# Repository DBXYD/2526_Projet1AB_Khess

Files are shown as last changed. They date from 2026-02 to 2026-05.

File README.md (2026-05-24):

# 🎓 2526_Projet1AB_Khess
> [!Note]
> Projet de 1ère année ENSEA sur une caisse enregistreuse pour la K-Fet.

> [!Important]
> Ce projet reprend en partie le travail de Matis Garbez, disponible sur [2425_Maker_CashRegister](https://github.com/Volcanite/2425_Maker_CashRegister/).




[]()

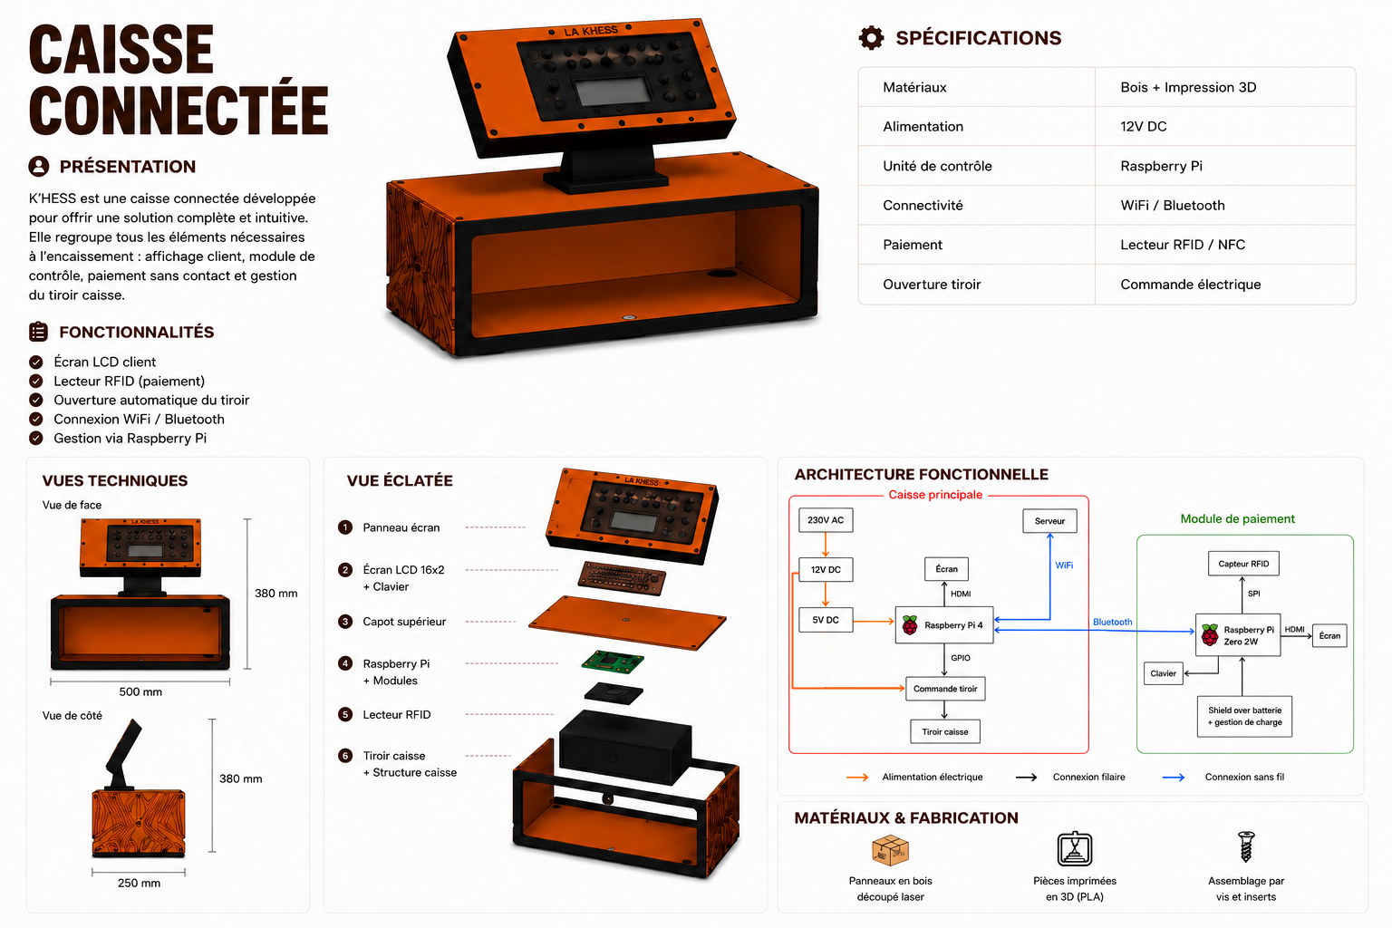
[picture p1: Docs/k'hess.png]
Illustration


## 📋 Sommaire
- [Cahier des charges](#cahier-des-charges)
	- [Caisse enregistreuse portable avec écran tactile](#caisse-enregistreuse-portable-avec-%C3%A9cran-tactile)
	- [Contraintes](#contraintes)
- [Hardware](#hardware)
- [Modèle 3D de la caisse](#mod%C3%A8le-3d-de-la-caisse)
- [Partie Logicielle (Software)](#partie-logicielle-software)
	- [Accès au Code Source et Déploiement](#acc%C3%A8s-au-code-source-et-d%C3%A9ploiement)
	- [Architecture de la Base de Données](#architecture-de-la-base-de-donn%C3%A9es)
- [Technologies utilisées](#technologies-utilis%C3%A9es)
- [Avancée du projet](#avanc%C3%A9e-du-projet)
	- [Journal de bord](#journal-de-bord)
	- [Ce qui a été réalisé](#ce-qui-a-%C3%A9t%C3%A9-r%C3%A9alis%C3%A9)
	- [Ce qui n'a pas (encore) été réalisé](#ce-qui-na-pas-encore-ete-r%C3%A9alis%C3%A9)
	- [Problèmes rencontrés et solutions trouvées](#probl%C3%A8mes-rencontr%C3%A9s-et-solutions-trouv%C3%A9es)
	- [Améliorations possibles](#am%C3%A9liorations-possibles)
- [Membres du projet](#membres-du-projet)
- [Licence](#licence)

## 📝 Cahier des charges 

### 📱 Caisse enregistreuse portable avec écran tactile 
* Interface utilisateur intuitive
* Gestion des produits et des prix
* Paiement avec carte étudiante

### ⚠️ Contraintes 
* Portabilité (batterie) : terminal de paiement
* Fiabilité des transactions
* Sécurité des données

## 🔧 Hardware 
Voir [Hardware/README.md](Hardware/README.md).

## 🖨️ Modèle 3D de la caisse 
La caisse automatique est consituée de 3 éléments :
- la caisse entière avec le socle
- le module de paiement
- le support pour la tablette
  
La modélisation 3D de ces différentes pièces à été réaliser avec le logiciel Onshape, voici les liens correspondant : 
* [Caisse entière avec socle](3D/Caisse%20entière%20avec%20socle.stl) 
* [Module paiement final](3D/Module%20payement%20final.stl)
* [Support tablette final](3D/Support%20tablette%20final.stl)

## 💻 Partie Logicielle (Software) 
Cette section regroupe l'ensemble du code source de l'application web de la caisse connectée, développée avec le framework **Django** (Python).

### 🔗 Accès au Code Source et Déploiement 

> **Note sur le dépôt :** Suite à des difficultés techniques lors de la synchronisation et de l'envoi du code sur le dépôt partagé de l'équipe, la version la plus récente et totalement à jour de l'application a été temporairement hébergée sur mon espace personnel.

* **Code source à jour :** Vous pouvez consulter et récupérer l'intégralité du projet en [cliquant directement sur ce lien vers mon dépôt personnel](https://github.com/zhang-estelle/DatabaseCashRegister).
* **Guide d'installation :** Pour faire fonctionner le code facilement sur votre machine, j'ai rédigé un guide pas-à-pas. Ce tutoriel recense également l'ensemble des blocages et des problèmes techniques que j'ai rencontrés durant le développement ainsi que leurs solutions. [Consulter le tutoriel de configuration Django](Docs/TutoDjango.md).

### 🗄️ Architecture de la Base de Données 

Le système s'appuie sur une base de données relationnelle structurée pour gérer les profils des étudiants, leurs soldes (cotisants ou non), le catalogue de la K-FET et l'historique des ventes.

* **Modèle Conceptuel :** Pour comprendre l'organisation de nos tables, vous pouvez [accéder au schéma graphique dbdiagram](Docs/dbdiagram.pdf).

## ⚙️ Technologies utilisées 
- Python
- Django
- Raspberry Pi
- KiCad
- Onshape
- Impression 3D

## ✅ Avancée du projet 

### 📓 Journal de bord 
Voir [Journal_de_bord.md](Docs/Journal_de_bord.md).

### ✅ Ce qui a été réalisé 
* Prise en main du projet
* Création des PCB
* Soudure des PCB
* Développement du site internet/ interface vendeur avec gestion des stocks, des commandes
* Modification 3D de la caisse en changeant les dimensions du socle soutenant la tablette
* Modélisation 3D du module de paiement avec plusieurs variantes afin de correspondre à la taille du PCB contenu à l'intérieur
* Développement du code du module de payement
* Modification 3D de la caisse en changeant le support tablette se mettant sur le socle
* Test du PCB

### ❌ Ce qui n'a pas (encore) été réalisé 
* Assemblage de l'ensemble

### 🛠️ Problèmes rencontrés et solutions trouvées 
Modélisation 3D:
- La taille du support de tablette était trop petite ( impossibilité de passer les câbles HDMI et USB vers la caisse automatique ). 
On a du imprimer plusieurs fois le support pour trouver la taille adéquate.
- Les trous pour fixer le support de tablette à son support n'étaient pas au bonne endroit après l'impression, on a du percer avec une perceuse les trous pour fixer le support correctement. 
- Problèmes usuels d'impression 3D.

### 💡 Améliorations possibles 
* Revoir le design de la caisse
* Améliorer le site internet

## 👥 Membres du projet 
|  |  |  |  |  |  |  |
| :---: | :---: | :---: | :---: | :---: | :---: | :---: |
| [@Ahhj93](https://github.com/Ahhj93)<br>Bryan-Sowanna Ing | [@NKRIMAT](https://github.com/NKRIMAT)<br>Naïm Krimat | [@Margaux-Lapl](https://github.com/Margaux-Lapl)<br>Margaux Laplante | [@StrangeKobe](https://github.com/StrangeKobe)<br>Rayan Laghouane | [@zhang-estelle](https://github.com/zhang-estelle)<br>Estelle Zhang | [@ClementJ493](https://github.com/ClementJ493)<br>Clément Jouneau | [@rim-05-mma](https://github.com/rim-05-mma)<br>Rim Bouchikhi |

## 📄 Licence 
Ce projet est distribué sous la licence MIT — voir [LICENSE](LICENSE).

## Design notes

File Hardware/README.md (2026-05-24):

# 🔧 Hardware
[]()
[]()
 
## 📋 Sommaire
- [Schéma d'architecture](#schema-architecture)
- [PCB_Khess_Cash_Drawer](#pcb_khess_cash_drawer)
    - [Schéma](#sch%C3%A9ma)
    - [Liste des composants du PCB](#liste-des-composants-du-pcb)
    - [Liste des composants autres](#liste-des-composants-autres)
    - [Justification des choix techniques](#justification-des-choix-techniques)
        - [Architecture d’alimentation](#architecture-dalimentation)
        - [Protections électriques](#protections-%C3%A9lectriques)
        - [Commande du tiroir caisse](#commande-du-tiroir-caisse)
    - [Ouverture du tiroir caisse (Raspberry Pi 4)](#ouverture-du-tiroir-caisse-raspberry-pi-4)
    - [PCB](#pcb)
- [PCB_Khess_Module_Payment](#pcb_khess_module_payment)
    - [Schéma](#sch%C3%A9ma-1)
    - [Liste des composants du PCB](#liste-des-composants-du-pcb-1)
    - [Liste des composants autres](#liste-des-composants-autres-1)
    - [Justification des choix techniques](#justification-des-choix-techniques-1)
        - [Raspberry Pi Zero 2W](#raspberry-pi-zero-2w)
        - [Interface RFID](#interface-rfid)
        - [Interface écran](#interface-%C3%A9cran)
        - [Clavier numérique](#clavier-num%C3%A9rique)
    - [PCB](#pcb-1)

## 🔎 Schéma d'architecture 

Voici une représentation Mermaid du schéma :

```mermaid
flowchart LR
    subgraph Caisse_principale[ Caisse principale ]
        A230(230V AC) --> A12(12V DC)
        A12 --> A5(5V DC)
        A5 --> RPi4[Raspberry Pi 4]
        A12 --> CmdT[Commande tiroir]
        CmdT --> Tiroir[Tiroir caisse]
        RPi4 -->|HDMI| Ecran[Ecran]
        RPi4 -->|GPIO| CmdT
        RPi4 -->|WiFi| Serveur[Serveur]
    end

    subgraph Module_paiement[ Module de paiement ]
        Shield[Shield + gestion batterie] --> RPi0[Raspberry Pi Zero 2W]
        RPi0 -->|HDMI| Ecran2[Ecran]
        RPi0 -->|SPI| RFID[Capteur RFID]
        RPi0 --> Clavier[Clavier]
    end

    RPi4 -->|Bluetooth| RPi0
```

## 🧾 PCB_Khess_Cash_Drawer 
### 🗺️ Schéma 
<details>
<summary>Afficher le schéma</summary>

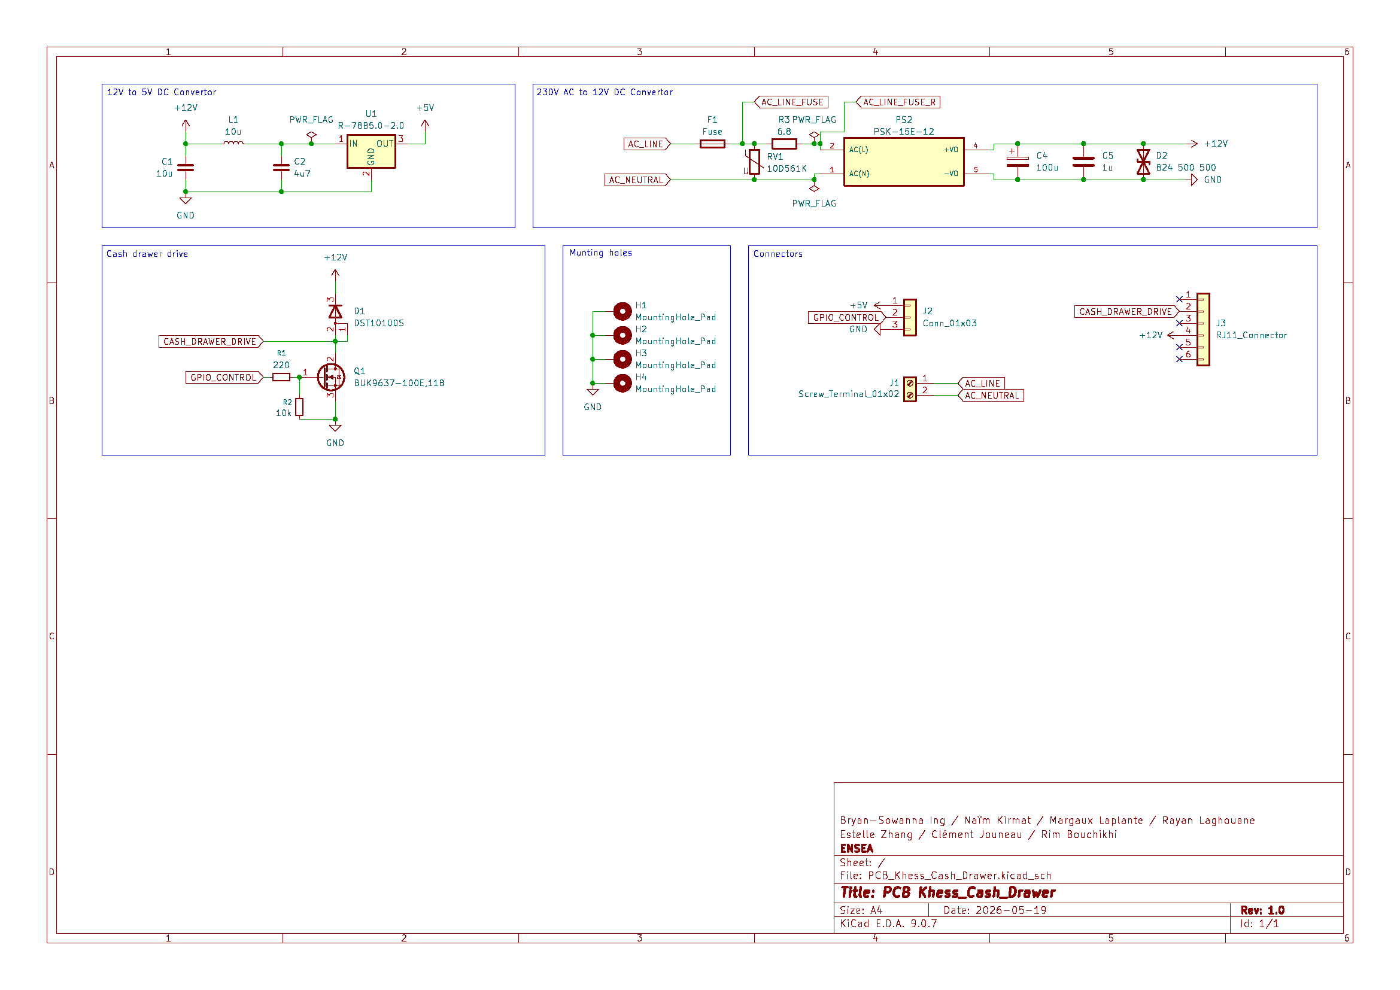
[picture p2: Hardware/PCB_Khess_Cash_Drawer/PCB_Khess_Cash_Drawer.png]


</details>

### 🔩 Liste des composants du PCB 

* Convertisseur 12V à 5V DC
    * 1 Convertisseur R-78B5.0-2.0 ([datasheet](/Datasheets/PCB_Khess_Cash_Drawer/R-78B-2.0.pdf))
    * 1 Condensateur 10uF
    * 1 Condensateur 4,7uF
    * 1 Bobine 10uH

* Conventisseur 230V à 12V DC
    * 1 Porte-fusible
    * 1 Convertisseur PSK-15E-12 ([datasheet](/Datasheets/PCB_Khess_Cash_Drawer/psk-15e.pdf))
    * 1 Condensateur 100uF
    * 1 Condensateur 1uF
    * 1 Diode TVS (824 500 500) ([datasheet](/Datasheets/PCB_Khess_Cash_Drawer/824500500.pdf))
    * 1 Résistance bobinée 6,8 Ohm (remplacée par un fil) ([datasheet](/Datasheets/PCB_Khess_Cash_Drawer/ac_ac-at_ac-ni.pdf))
    * 1 Varistance TVS 10D561K (non mise) ([datasheet](/Datasheets/PCB_Khess_Cash_Drawer/mov10d.pdf))

* Commande du tiroir caisse
    * 1 Diode DST10100S ([datasheet](/Datasheets/PCB_Khess_Cash_Drawer/littelfuse-rectifier-DST10100S-datasheet.pdf))
    * 1 Transistor BUK9637-100E,118 ([datasheet](/Datasheets/PCB_Khess_Cash_Drawer/BUK9637-100E.pdf))
    * 1 Résistance 220 Ohm
    * 1 Résistance 10k Ohm

* Connecteurs
    * 1 Connecteur 01x03
    * 1 Connecteur RJ11, remplacée par 1 Connecteur 01x02
    * 1 Bornier à vis 01x02
    * 1 Écran tactile

### 📦 Liste des composants autres 

* Tiroir caisse avec connecteur standard RJ11, remplacée par des connecteurs simples
* Câble d'alimentation
* Raspberry Pi 4

## ⚙️ Justification des choix techniques 

### 🔌 Architecture d’alimentation 

L’alimentation du système est réalisée en deux étapes afin d’assurer une conversion efficace et stable :

1. Conversion du secteur 230V AC vers 12V DC ;
2. Conversion du 12V DC vers 5V DC.

Le module **PSK-15E-12** a été choisi car il permet :
- une intégration compacte directement sur le PCB ;
- une puissance suffisante pour alimenter le tiroir caisse et les circuits logiques.

Le convertisseur **R-78B5.0-2.0** a été préféré à un régulateur linéaire classique pour son excellent rendement énergétique. Cela permet - d’éviter l’ajout d’un dissipateur thermique ;
- d’assurer une alimentation stable du Raspberry Pi.

Les condensateurs et la bobine de filtrage permettent de réduire les parasites haute fréquence et d’améliorer la stabilité des tensions d’alimentation.

### 🛡️ Protections électriques 

Plusieurs composants de protection ont été ajoutés afin d’améliorer la robustesse du système :

- le porte-fusible protège la carte en cas de court-circuit ;
- la diode TVS protège contre les surtensions transitoires ;
- la varistance devait initialement renforcer la protection contre les pics secteur ;
- les condensateurs participent au filtrage des perturbations électromagnétiques.

Ces protections sont importantes car le système est directement relié au secteur et pilote une charge inductive.

### ⚡ Commande du tiroir caisse 

Le tiroir caisse est commandé via un MOSFET de puissance **BUK9637-100E**. Ce composant a été choisi pour :
- sa faible résistance à l’état passant ;
- sa capacité à commuter des courants importants ;
- sa compatibilité avec les niveaux logiques du Raspberry Pi.

La diode **DST10100S** agit comme diode de roue libre afin d’absorber les surtensions générées lors de la coupure du courant dans l’électroaimant du tiroir caisse.

La résistance de 220 Ω limite le courant de commande du MOSFET tandis que la résistance de 10 kΩ garantit son extinction au démarrage.

### 🚪 Ouverture du tiroir caisse (Raspberry Pi 4) 

L’ouverture du tiroir caisse se fait via le PCB :

1. La **Raspberry Pi 4** envoie un signal de commande sur un **GPIO** ;
2. Le GPIO pilote la grille du **MOSFET** sur le PCB ;
3. Le MOSFET commute l’alimentation **12V** de l’électroaimant du tiroir ;
4. Le tiroir caisse s’ouvre pendant l’impulsion.

Nous n’avions pas de port **RJ11** disponible sur notre montage.  
Nous avons donc remplacé les connecteurs RJ11 par des **pinheaders**.

### 🧩 PCB 
<details>
<summary>Voir PCB (face côté avant)</summary>

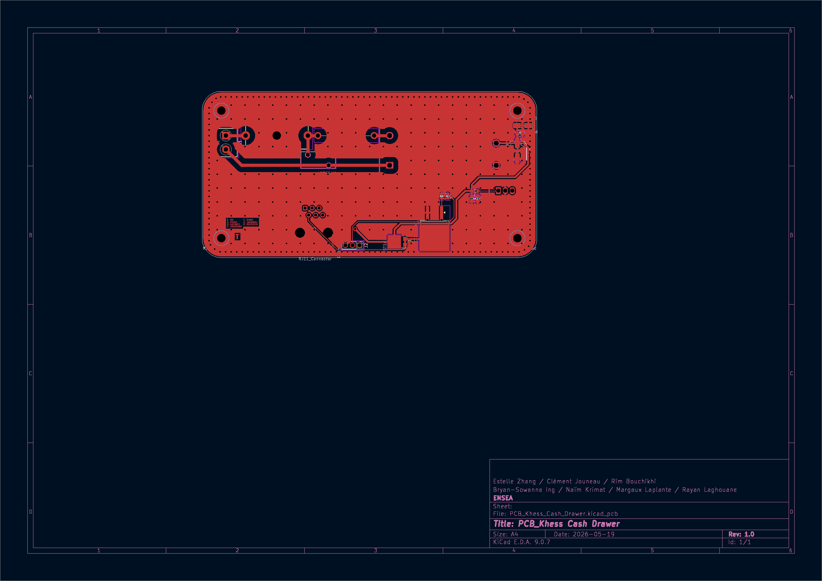
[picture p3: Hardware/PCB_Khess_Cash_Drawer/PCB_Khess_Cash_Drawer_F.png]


</details>

<details>
<summary>Voir PCB (face arrière)</summary>

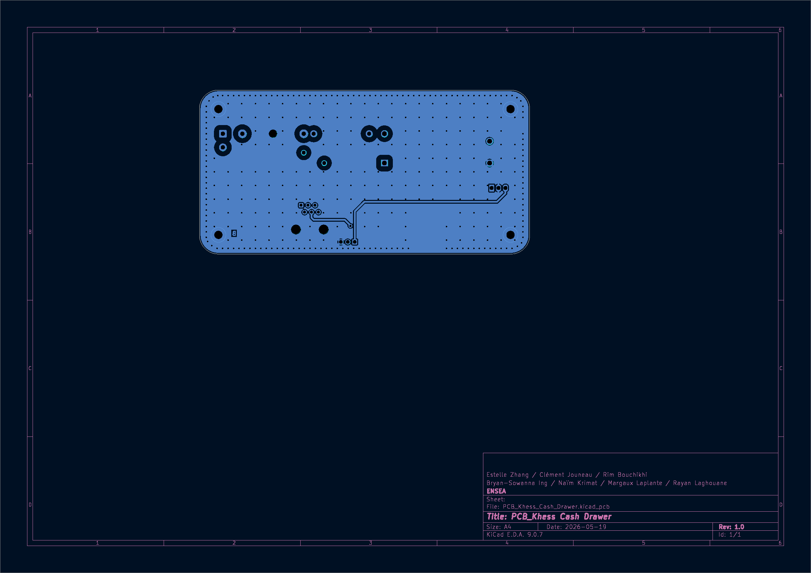
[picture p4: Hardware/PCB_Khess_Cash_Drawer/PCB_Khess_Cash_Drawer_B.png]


</details>

---

## 🧾 PCB_Khess_Module_Payment 
### 🗺️ Schéma 
<details>
<summary>Afficher le schéma</summary>

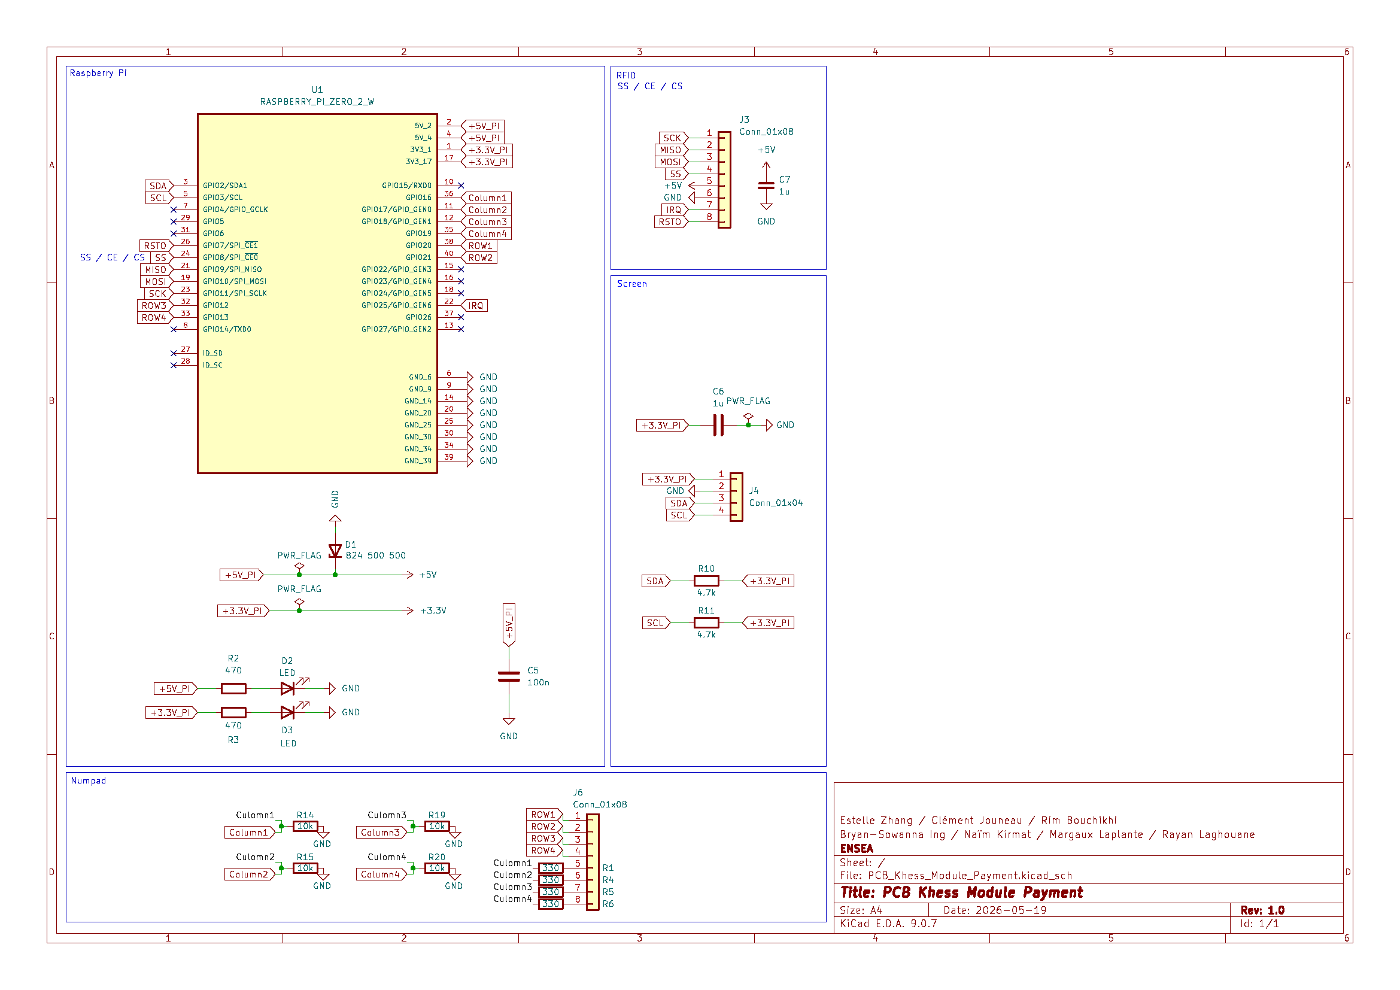
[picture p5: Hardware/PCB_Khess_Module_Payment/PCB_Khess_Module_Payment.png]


</details>

### 🔩 Liste des composants du PCB 

* Raspberry Pi
    * 1 Connecteur 02x20
    * 1 Diode TVS (824 500 500) ([datasheet](/Datasheets/PCB_Khess_Cash_Drawer/824500500.pdf))
    * 2 Résistances 470 Ohm
    * 2 LED
    * 1 Condensateur 100nF

* RFID
    * 1 Connecteur 01x08
    * 1 Condensateur 1uF

* Écran
    * 1 Condensateur 1uF
    * 1 Connecteur 01x04
    * 2 Résistances 4,7k Ohm

* Clavier numérique
    * 4 Résistances 10k Ohm
    * 4 Résistances 330 Ohm
    * 1 Connecteurs 01x08

### 📦 Liste des composants autres 

* 1 Raspberry Zero 2W
* 1 Écran tactile
* 1 Clavier numérique
* 1 Capteur RFID
* 1 Shield pour gérer une batterie

### ⚙️ Justification des choix techniques 

#### 🖥️ Raspberry Pi Zero 2W 

Le Raspberry Pi Zero 2W a été choisi comme unité centrale du module de paiement pour plusieurs raisons :
- faible consommation énergétique ;
- connectivité Wi-Fi intégrée ;
- puissance suffisante pour gérer l’interface utilisateur et les périphériques.

#### 🛰️ Interface RFID 

Le module RFID permet l’identification sans contact des utilisateurs.

Le connecteur 01x08 qui permet la comminication via le bus SPI, facilite le remplacement ou la maintenance du module RFID. Le condensateur de 1 µF améliore la stabilité de son alimentation et limite les perturbations lors des communications.

#### 🖱️ Interface écran 

L’écran tactile est connecté via une interface dédiée afin de simplifier le montage.

Les résistances de pull-up de 4,7 kΩ servent de résistances de tirage pour les lignes de communication utilisées en I2C.

Le condensateur de 1 µF stabilise l’alimentation de l’écran et réduit les parasites.

#### 🔢 Clavier numérique 

Le clavier numérique permet une interaction simple avec l’utilisateur et sert dans le cas où l'utilisateur ne possède pas sa carte.

Les résistances de 10 kΩ sont utilisées comme résistances de rappel afin d’éviter les états flottants sur les entrées numériques.

Les résistances de 330 Ω limitent le courant dans certaines lignes d’interface et protègent les GPIO du Raspberry Pi.

#### 🛡️ Protection et fiabilité 

La diode TVS protège les circuits contre les surtensions et les décharges électrostatiques.

Le condensateur de 100 nF placé près du Raspberry Pi assure un découplage haute fréquence.
Les LED servent d’indicateurs visuels.

### 🧩 PCB 
<details>
<summary>Voir PCB (face avant)</summary>

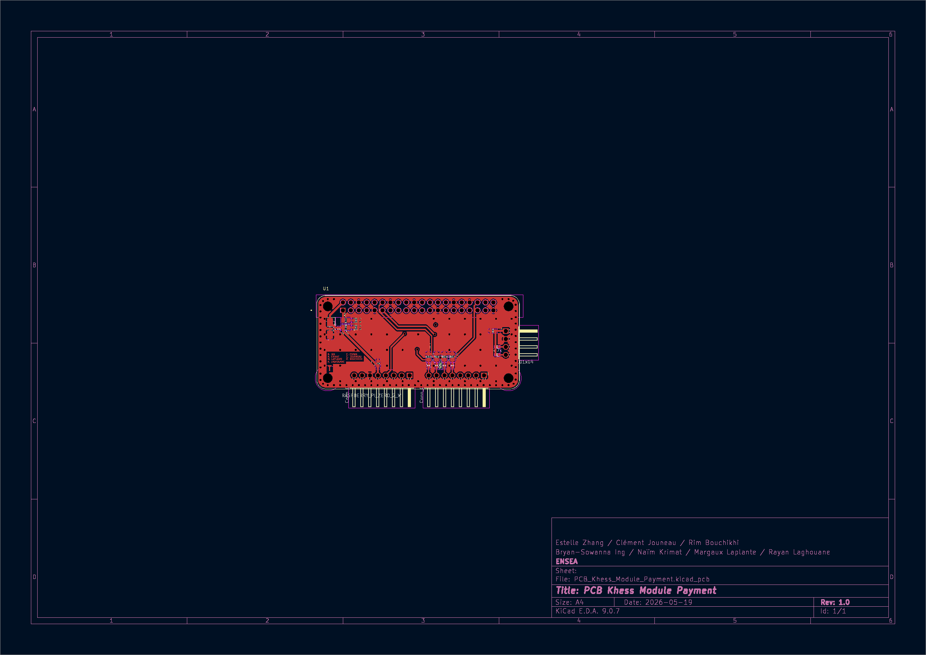
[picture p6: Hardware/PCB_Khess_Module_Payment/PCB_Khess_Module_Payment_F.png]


</details>

<details>
<summary>Voir PCB (détails couche intérieur 1)</summary>

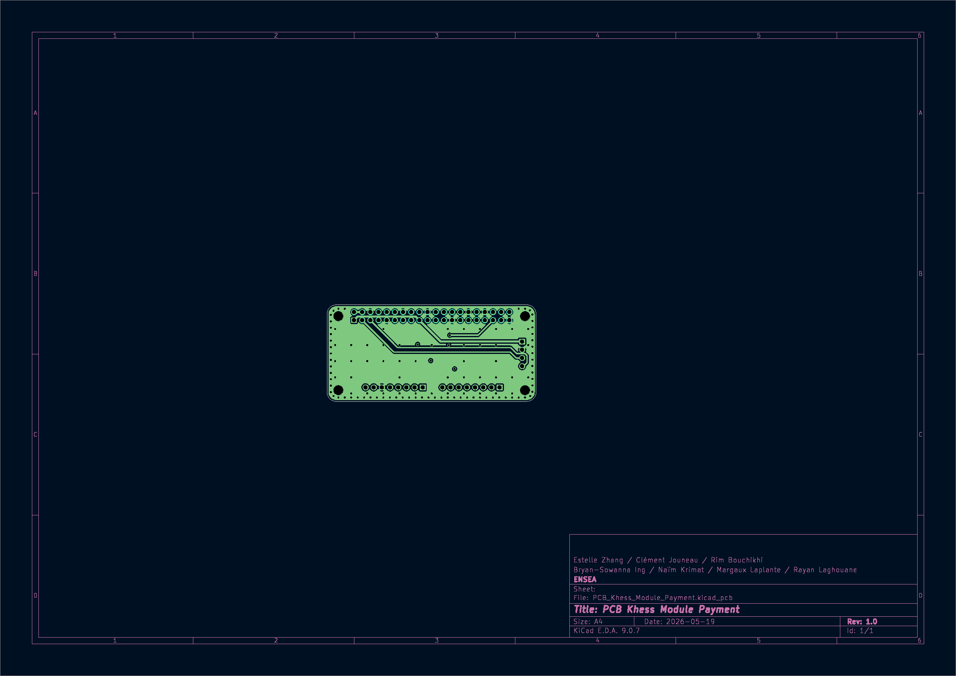
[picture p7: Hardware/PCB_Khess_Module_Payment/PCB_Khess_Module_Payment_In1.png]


</details>

<details>
<summary>Voir PCB (détails couche intérieur 2)</summary>

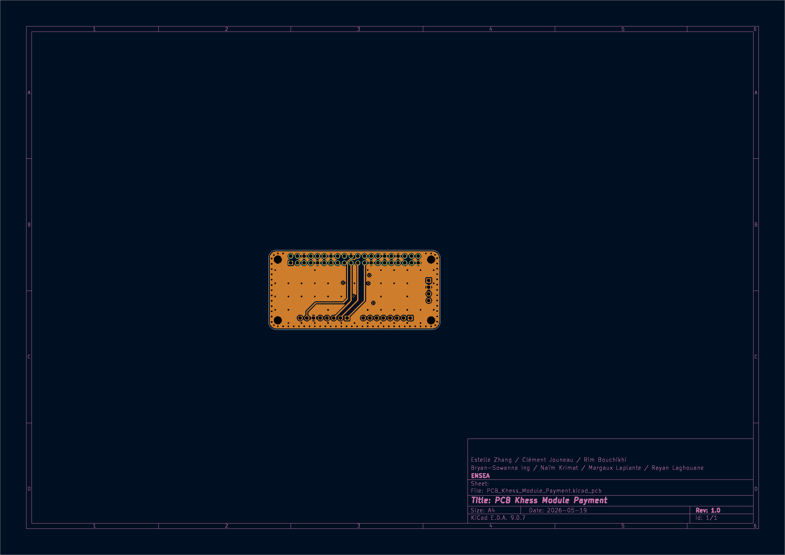
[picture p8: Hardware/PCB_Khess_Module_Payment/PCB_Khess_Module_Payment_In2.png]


</details>

<details>
<summary>Voir PCB (face arrière)</summary>

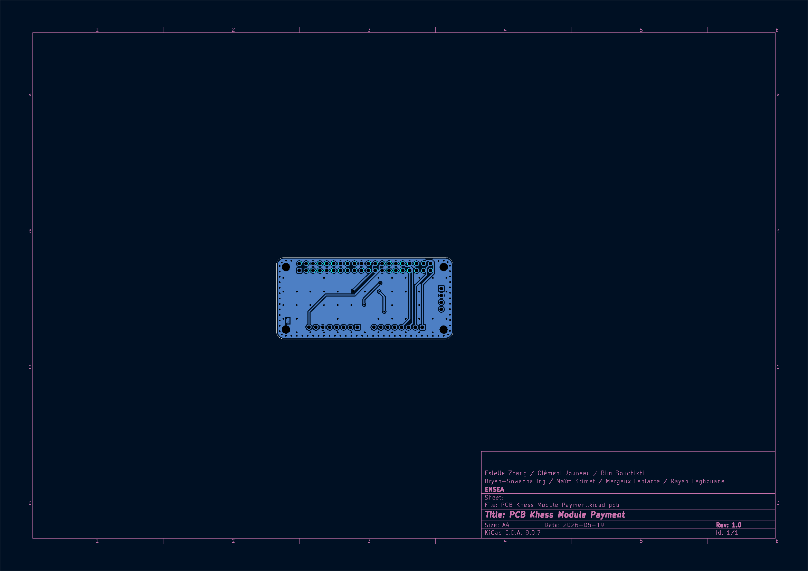
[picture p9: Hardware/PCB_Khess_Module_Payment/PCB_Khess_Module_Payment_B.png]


</details>

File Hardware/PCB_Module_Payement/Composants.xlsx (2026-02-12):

Composoants disponibles en stock | Composants manquants | Alternatives possibles
Microcontrôleur : STM32G431CBU6 | Transistor NPN MMBT2222A | RE1C002UNTCL
Régulateur 3.3V : BU33SD5WG-TR | Connecteur USB-C: USB_C_Receptacle_USB2.0
Convertisseur Buck 5V: power DC-DC_Converters Wurth 171013801 10 0,85V to 13V Step-Down | Connecteur: J (USB-C): USB_C_Receptacle_USB2.0
Protection USB : USBLC6-2SC6 | Connecteur J7 (ST-Link): Conn_ST_GDC14
Diodes Schottky : FSV340AF (x2)
 | resistance 1.7kΩ (x3)
 | resistance 49.9kΩ (x1)
Connecteur Numpad (1x08) | resistance 168kΩ (x1)
Connecteur RFID (1x08) | resistance 510Ω (x1)
Connecteur Bluetooth (1x06)
Connecteur Ecran (1x04) | Buzzer 5V
Connecteur Batterie (1x02)
 | Bouton Switch: Button_Switch_SMD:SW_Push_1P1T_NO_CK_KSC6xxJ (x3)
inductance 39nH: 7447860139 (x1)
capacité 100nF: 885012205086 (x8)
capacité 1uF: 885012206076 (x7)
capacité 4.7uF: 885012106012 (x1)
capacité 10uF: 885012214001 (x1)
capacité 47uF: 865060443004 (x1)
resistance 10kΩ: RC0805FR-0710KL (x7)
resistance 5.1kΩ: RC0805FR-075K1 (x2)
resistance 1kΩ: RC0805FR-071KL (x1)
Wurth 1501511 pour les LEDS
Wurth 1583001 pour les LEDS

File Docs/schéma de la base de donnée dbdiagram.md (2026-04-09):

Voici le code : 

```bash
// --- TABLES UTILISATEURS (Bleu) ---
Table User {
  id integer [primary key]
  username varchar
}

Table users_custom {
  id integer [primary key]
  user_id integer [ref: - User.id]
  first_name varchar
  last_name varchar
  sold float
  class_name varchar
  nb_transaction integer
  role varchar // admin, respo, student
  status varchar // cotisant, non_cotisant, prof
  created_at timestamp
}

// --- GESTION DES PRODUITS ET MENUS (Vert) ---
Table Article {
  id integer [primary key]
  name varchar
  quantity integer
  type varchar // le midi, boisson, snack, viennoiseries
  price_cotisant float
  price_non_cotisant float
}

Table Menu {
  id integer [primary key]
  name varchar
  price float
}

Table MenuDetails {
  id integer [primary key]
  menu_id integer [ref: > Menu.id]
  article_id integer [ref: > Article.id]
}

// --- SYSTÈME DE VENTES (Orange) ---
Table Transaction {
  id integer [primary key]
  user_id integer [ref: > User.id]
  price float
  created_at timestamp
}

Table TransactionDetails {
  id integer [primary key]
  transaction_id integer [ref: > Transaction.id]
  user_id integer [ref: > User.id]
  article_id integer [ref: > Article.id]
  type varchar
  quantity integer
  price float
  payment_type varchar // cash, card
  created_at timestamp
}

// --- COMPTABILITÉ (Gris) ---
Table Cash {
  id integer [primary key]
  sold_cash float
  gain_card float
  gain_cash float
  total float
}
```

1 (Obligatoire) : L'élément doit exister. Un badge de la K-FET est forcément attaché à 1 personne. Il ne peut pas être "orphelin".
0..1 (Optionnel) : L'élément peut exister ou non. Une personne peut avoir 0 badge (si elle n'est pas inscrite) ou 1 badge maximum.

## Les différents liens : 

1. User ↔ users_custom : Un utilisateur ne peut avoir qu'un seul profil users_custom car son solde et son statut (cotisant ou non) doivent être uniques pour éviter les erreurs de compte.
 
3. User ↔ Transaction : Un utilisateur peut faire plusieurs transactions car il peut venir acheter à la K-FET plusieurs fois par jour ou par an.

4. Transaction ↔ TransactionDetails : Une seule transaction peut avoir plusieurs détails car un client peut acheter plusieurs articles différents en un seul passage en caisse.

5. Article ↔ TransactionDetails : Un même article peut être relié à plusieurs lignes de détails car le même produit (ex: un café) est vendu à plein de clients différents.

6. Menu ↔ MenuDetails : Un menu peut être lié à plusieurs articles (via les détails) car une "Formule Midi" est composée de plusieurs produits comme un plat, une boisson et un dessert.

7. Article ↔ MenuDetails : Un article peut appartenir à plusieurs menus car un même soda peut faire partie de la "Formule Snack" et de la "Formule Midi".

---
### Schéma Visuel
Mon Schéma de Base de Données

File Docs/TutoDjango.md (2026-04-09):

# 🛒 Projet Caisse Enregistreuse - Tuto Django

> **Projet Ingénieur** : Système de gestion de commandes et de base de données.

Ce projet permet de gérer une caisse enregistreuse via une interface web. Il utilise **Django** pour le backend et une base de données **SQLite**.

---

## 🛠️ Installation et Configuration

Pour faire fonctionner le projet sur votre machine (Linux/Ubuntu), suivez ces étapes dans votre terminal de VS code.

### 1. Préparation de l'environnement virtuel
```bash
# Crée le dossier de l'environnement virtuel nommé 'venv'
python3 -m venv venv

# Active l'environnement (indispensable avant chaque séance de travail)
# Vous devriez voir (venv) apparaître à gauche de votre curseur
source venv/bin/activate
```

### 2. Installation de Django et des modules
Une fois l'environnement activé, installez les bibliothèques Python indispensables :
```bash
# Installe le framework web principal
pip install django

# Installe le module pour l'authentification centralisée de l'école
pip install django-cas-ng
```

### 3. Lancement du serveur de développement
Accédez au dossier contenant le fichier manage.py et lancez le moteur du site :
```bash
# Se déplacer dans le dossier racine du projet
cd DatabaseCashRegister

# Démarre le serveur local
python3 manage.py runserver
```
Le site est maintenant accessible sur votre navigateur à l'adresse : http://127.0.0.1:8000/

### 🧭 Navigation sur le site

Pour accéder aux différentes pages, vous devez ajouter le chemin correspondant à la fin de l'URL `http://127.0.0.1:8000/`. Vous pouvez retrouver ces chemins dans le fichier urls.py sous la variable urlpatterns.

Voici les accès principaux pour ce projet :

| Page | Chemin à ajouter | URL complète |
| :--- | :--- | :--- |
| **Accueil** | `/` | http://127.0.0.1:8000/ |
| **Administration** | `admin/` | http://127.0.0.1:8000/admin/ |
| **Caisse** | `cash_register_page/` | http://127.0.0.1:8000/cash_register_page/ |
| **Présentation** | `présentation/` | http://127.0.0.1:8000/présentation/ |

### 🛠️ Résolution du problème "DoesNotExist" (Page d'accueil vide)

Si l'adresse http://127.0.0.1:8000/admin/ fonctionne mais que la page d'accueil http://127.0.0.1:8000/ affiche une erreur, c'est parce que votre utilisateur n'est pas encore enregistré dans la table users_custom.

Voici comment régler ça :
1. Connectez-vous sur l'interface d'administration : http://127.0.0.1:8000/admin/.
2. Dans la section Users_Custom, cliquez sur Add (Ajouter).
3. Remplissez les informations en veillant à ce que le nom d'utilisateur corresponde exactement à celui avec lequel vous essayez de vous connecter.
4. Enregistrez, puis retournez sur la page d'accueil.

### 🗄️ Visualiser la Base de Données sur VS Code
Pour explorer les tables (produits, ventes, utilisateurs) sans quitter votre éditeur de code :
1. Allez dans l'onglet Extensions de VS Code (icône carrée à gauche).
2. Recherchez et installez les extensions : SQLite et SQLite Viewer.
3. Une fois installées, vous pourrez ouvrir le fichier db.sqlite3 pour voir les données sous forme de tableaux clairs.

### 🔐 Créer ou Modifier un compte Administrateur
Si vous avez une erreur 403 Forbidden ou si votre compte n'a pas les droits, vous pouvez forcer les privilèges "Staff" (Directeur) via la console Python de Django.
1. Entrez dans le mode "Shell" (console interactive)
```bash
python3 manage.py shell
```
2. Copiez et collez ces lignes de code une par une :
```bash
from django.contrib.auth.models import User
u = User.objects.get(username='ton_nom_utilisateur_ensea')
u.is_staff = True
u.is_superuser = True
u.save()
exit()
```
### 🖼️ Changer l'image d'un produit

1. **Nommer l'image** : Renommez votre fichier image exactement comme le nom du produit dans l'interface Administration (ex: `coca cola.png`). Attention aux espaces et aux minuscules !
2. **Ajouter le fichier** : Déposez votre image dans le dossier VS Code suivant : `users/static/users/images/`
3. **Modifier le code** : Dans votre fichier HTML `cash_register.html`, remplacez les lignes `<img>` par :
   `<img src="{% static 'users/images/' %}{{ article.name }}.png" alt="{{ article.name }}" class="img-fluid mb-2" style="max-height: 100px;">`
4. **Actualiser** : Enregistrez votre fichier (**CTRL + S**) puis rafraîchissez le navigateur avec **CTRL + F5** pour forcer le chargement des nouvelles images.

Si vos images sont au format .jpg, remplacez simplement .png par .jpg à la fin de la ligne de code ci-dessus. Toutes vos photos devront alors avoir le même format.

### 📂 Ajouter une nouvelle catégorie de produits

Pour ajouter un nouvel onglet (ex: Viennoiseries) et afficher les produits correspondants, il faut suivre ces étapes suivantes :

1. Modifier le Modèle (models.py)
 Ajoutez la catégorie dans la base de données.

```bash
TYPE_CHOICES = [
    ('sandwich', 'Sandwich'),
    ('boisson', 'Boisson'),
    ('snack', 'Snack'),
    ('viennoiseries', 'Viennoiseries'), # <-- Nouvelle ligne
]
```

2. Mettre à jour la Vue (views.py)
Mise à jour de la liste pour le menu latéral.
```bash
def cash_register_page(request):
    articles = Article.objects.all()
    categories = ['Tout', 'Menu', 'Sandwich', 'Snack', 'Boisson', 'Viennoiseries'] 
    return render(request, 'users/cash_register.html', {
        'article_items': articles, 
        'categories': categories
    })
]
```
3.Créer la section dans le HTML (cash_register.html)
Copie ce bloc à la suite des autres : 
```bash
<div id="viennoiseries" class="category-section">
    <h2 class="mt-4">Viennoiseries</h2>
    <div class="row">
        {% for article in article_items %}
            {% if article.type == 'viennoiseries' %}
                <div class="col-md-2 mb-4">
                    <button class="btn btn-light w-100 shadow-sm rounded" style="height: 200px;">
                        <div class="d-flex flex-column align-items-center">
                            <img src="{% static 'users/images/' %}{{ article.name }}.png" class="img-fluid mb-2" style="max-height: 100px;">
                            <span class="fw-bold">{{ article.name }}</span>
                            <span class="text-muted">{{ article.price }} €</span>
                        </div>
                    </button>
                </div>
            {% endif %}
        {% endfor %}
    </div>
</div>
```
Sauvegardez (CTRL+S) et redémarrez le serveur.

### 💳 Implémenter une double tarification (Cotisant vs Non-Cotisant)

1. models.py (La Base)
C'est ici que l'on définit les deux colonnes de prix.
```bash
class Article(models.Model):
    name = models.CharField(max_length=255)
    quantity = models.IntegerField(default=0)
    TYPE_CHOICES = [('le midi', 'Le Midi'), ('boisson', 'Boisson'), ('snack', 'Snack'),('viennoiseries', 'Viennoiseries')]
    type = models.CharField(max_length=50, choices=TYPE_CHOICES, default='snack')
    # Les deux nouveaux champs de prix
    price_cotisant = models.FloatField(default=0)
    price_non_cotisant = models.FloatField(default=0)
```
2. admin.py (L'interface de gestion)
```bash
@admin.register(Article)
class ArticleAdmin(admin.ModelAdmin):
    list_display = ('name', 'quantity', 'type', 'price_cotisant', 'price_non_cotisant')
    list_filter = ('type',)
```

3. views.py (La Logique de sélection)

```bash
## Récupération des articles :
    article_items = []
    for article in article_data:
        # Condition pour choisir le prix
        if user_data.status == 'Cotisant':
            prix_final = article.price_cotisant
        else:
            prix_final = article.price_non_cotisant
            
        article_items.append({
            'name': article.name, 
            'quantity': article.quantity, 
            'type': article.type, 
            'price': prix_final
        })
```

4. Les commandes Terminal (Indispensables)
```bash
python manage.py makemigrations
python manage.py migrate
python manage.py runserver
```
### 🖥️ Afficher deux tarifs (C & NC) sur l'interface Web 

1. Dans views.py
On change juste ce qu'on envoie dans le dictionnaire pour inclure les deux variables.
```bash
article_items.append({
      'name': article.name,
      'type': article.type,
      'price_c': article.price_cotisant,     
      'price_nc': article.price_non_cotisant
```

2. Dans cash_register.html
```bash
<span class="text-muted" style="font-size: 0.8em;">Cotisant : {{ article.price_c }} €</span>
<span class="text-muted" style="font-size: 0.8em;">Non Cotisant : {{ article.price_nc }} €</span>
```

### 🛠️ Corriger l'erreur "NaN" après l'ajout du double prix

Le problème vient du fait que ton JavaScript récupérait le prix en lisant le texte à l'intérieur du bouton. Comme il y a maintenant deux prix affichés (Cotisant et Non Cotisant), le script mélange tout.

1.Préparer le bouton dans le HTML
Dans ton fichier cash_register.html, modifie la balise <button> de chaque section (Tout, Snack, Boisson, etc.) comme ceci :

```bash
<button class="btn btn-light w-100 shadow-sm rounded article-btn" 
       style="height: 200px;"
       data-name="{{ article.name }}"
       data-price="{% if user_data.status == 'cotisant' %}{{ article.price_c }}{% else %}{{ article.price_nc }}{% endif %}">
   <div class="d-flex flex-column align-items-center">
       <img src="{% static 'users/images/' %}{{ article.name }}.png" alt="{{ article.name }}" class="img-fluid mb-2" style="max-height: 100px;">
       <span class="fw-bold">{{ article.name }}</span>
        
       <span class="text-muted" style="font-size: 0.8em;">Cotisant : {{ article.price_c }} €</span>
       <span class="text-muted" style="font-size: 0.8em;">Non Cotisant : {{ article.price_nc }} €</span>
   </div>
</button>
```
2. Modifier le JavaScript (La lecture du prix) :
Il faut maintenant dire à ton script de ne plus lire le texte affiché, mais de lire l'attribut data-price que nous venons de créer.
Cherche la partie <script> en bas de ton fichier et remplace le bloc qui gère le clic par celui-ci :

```bash
document.querySelectorAll('.article-btn').forEach(button => {
    button.addEventListener('click', function () {
    // NEW: On récupère les données "data-name" et "data-price" du bouton
    const name = this.getAttribute('data-name');
    const price = parseFloat(this.getAttribute('data-price'));

// On vérifie que le prix est bien un chiffre (pour éviter le NaN)
    if (!isNaN(price)) {
       addToOrder(name, price);
    } else {
       alert("Erreur : Le prix de cet article n'est pas bien défini.");
}
```

### 🥐 Afficher une Nouvelle Catégorie (Viennoiseries)

Lorsque tu ajoutes une catégorie comme "Viennoiseries" dans ton projet, il ne suffit pas de créer l'onglet ; il faut dire à Django comment filtrer les articles pour qu'ils apparaissent au bon endroit.
Pour éviter les erreurs de majuscules ou de pluriels (ex: "Viennoiserie" vs "viennoiseries"), on utilise le filtre |lower.
Dans ton fichier cash_register.html, copie colle dans la catégorie vienoiserie : 

```bash
<div id="viennoiserie" class="category-section">
                <h2>Viennoiseries</h2>
                <div class="row">
                    {% for article in article_items %}
                        {% if article.type|lower == 'viennoiserie' or article.type|lower == 'viennoiseries' %}
                             <div class="col-md-2 mb-4">
                                 <button class="btn btn-light w-100 shadow-sm rounded article-btn" 
                                         style="height: 200px;"
                                         data-name="{{ article.name }}"
                                        data-price="{% if user_data.status|lower == 'cotisant' %}{{ article.price_c }}{% else %}{{ article.price_nc }}{% endif %}">
                                     <div class="d-flex flex-column align-items-center">
                                             <img src="{% static 'users/images/' %}{{ article.name }}.png" alt="{{ article.name }}" class="img-fluid mb-2" style="max-height: 100px;">
                                             <span class="fw-bold">{{ article.name }}</span>
                                             <span class="text-muted" style="font-size: 0.8em;">Cotisant : {{ article.price_c }} €</span>
                                            <span class="text-muted" style="font-size: 0.8em;">Non Cotisant : {{ article.price_nc }} €</span>
                                     </div>
                                </button>
                            </div>
                         {% endif %}
                    {% endfor %}
                 </div>
            </div>
```

### Creéer un nouveau profil

```bash
@receiver(post_save, sender=User)
def create_user_profile(sender, instance, created, **kwargs):
    """
    Très important pour le CAS ! 
    Dès qu'un nouvel "User" se connecte pour la première fois via le système de l'école,
    ce signal lui crée automatiquement son "UserCustom" (son profil avec le solde à 0).
    """
    if created:
        UserCustom.objects.create(
            user=instance,
            first_name=instance.first_name or "Nouvel",
            last_name=instance.last_name or "Utilisateur"
        )

```

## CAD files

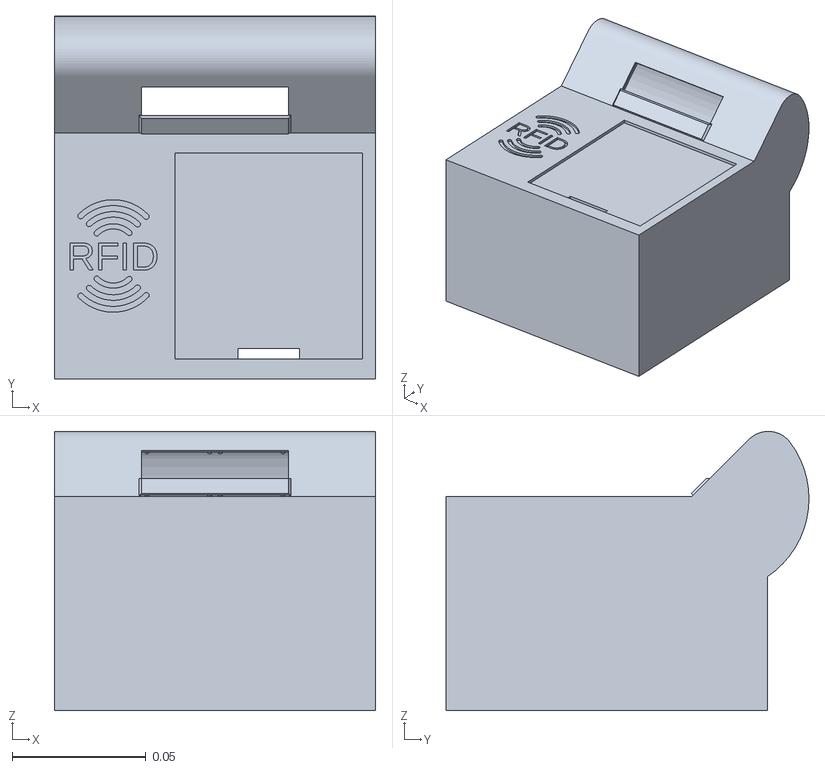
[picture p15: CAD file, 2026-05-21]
3D/Module payement final.stl
0.12 x 0.136 x 0.104

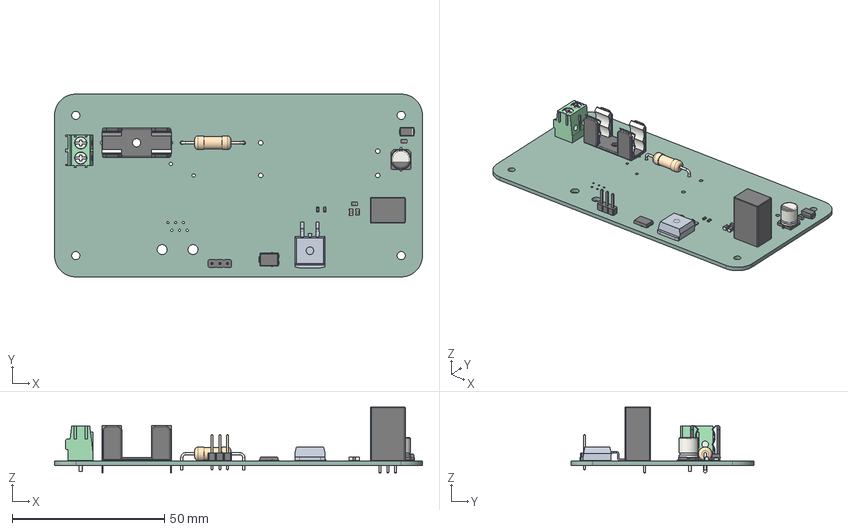
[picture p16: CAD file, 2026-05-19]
Hardware/PCB_Khess_Cash_Drawer/PCB_Khess_Cash_Drawer.step
121.0 x 60.1 x 21.6 mm
PinHeader_1x03_P2.54mm_Vertical
TerminalBlock_Phoenix_PT-1,5-2-5.0-H_1x02_P5.00mm_Horizontal
D_SMA
R_0603_1608Metric x 2
Converter_DCDC_RECOM_R-78B-2.0_THT
PCB_Khess_Cash_Drawer 1.6.1
CP_Elec_6.3x7.7
TO-277A
R_Axial_DIN0414_L11.9mm_D4.5mm_P20.32mm_Horizontal
Fuseholder_Cylinder-5x20mm_Schurter_0031_8201_Horizontal_Open
C_0805_2012Metric x 3
L_0805_2012Metric
PCB_Khess_Cash_Drawer_PCB

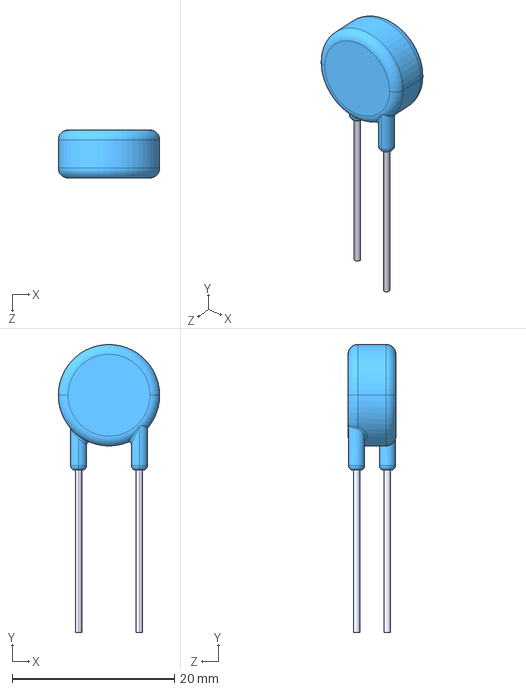
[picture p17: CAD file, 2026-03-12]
Hardware/PCB_Khess_Cash_Drawer/Symbol_and_Footprint/MOV-10D561K/MOV-10D561K.step
12.5 x 35.5 x 5.90 mm

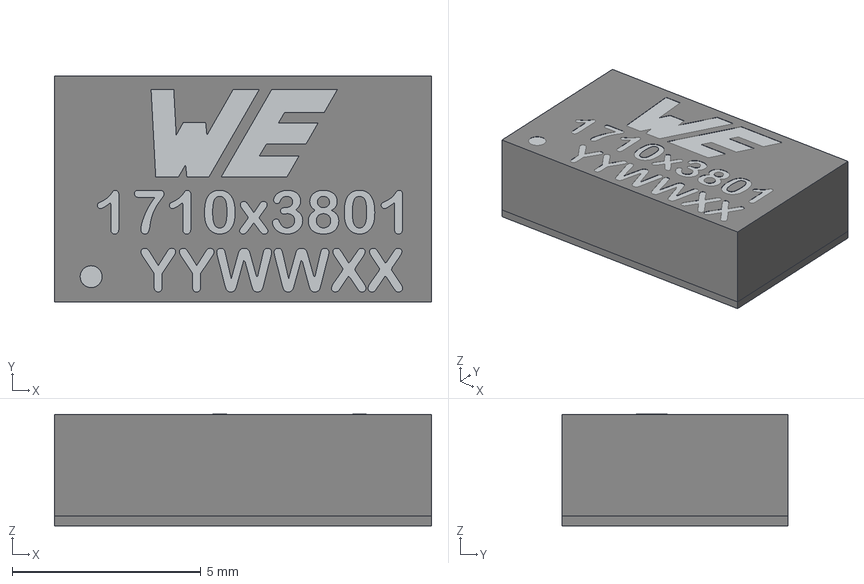
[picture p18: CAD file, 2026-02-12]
Hardware/PCB_Module_Payement/Wurth_171013801.stp
10.0 x 6.00 x 2.97 mm
Base
Pads

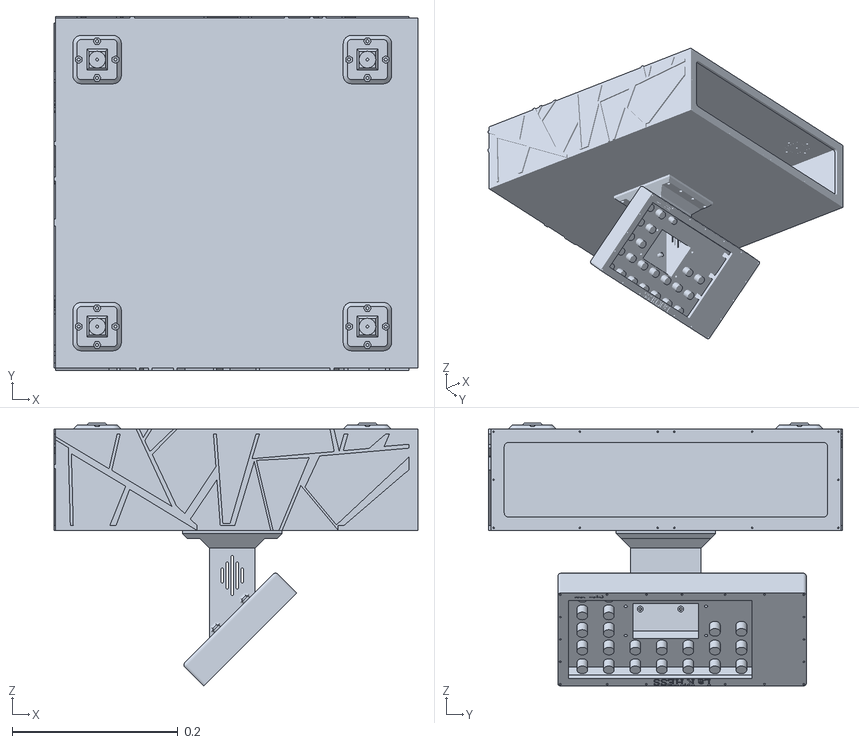
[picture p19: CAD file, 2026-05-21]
3D/Caisse entière avec socle.stl
0.439 x 0.427 x 0.317

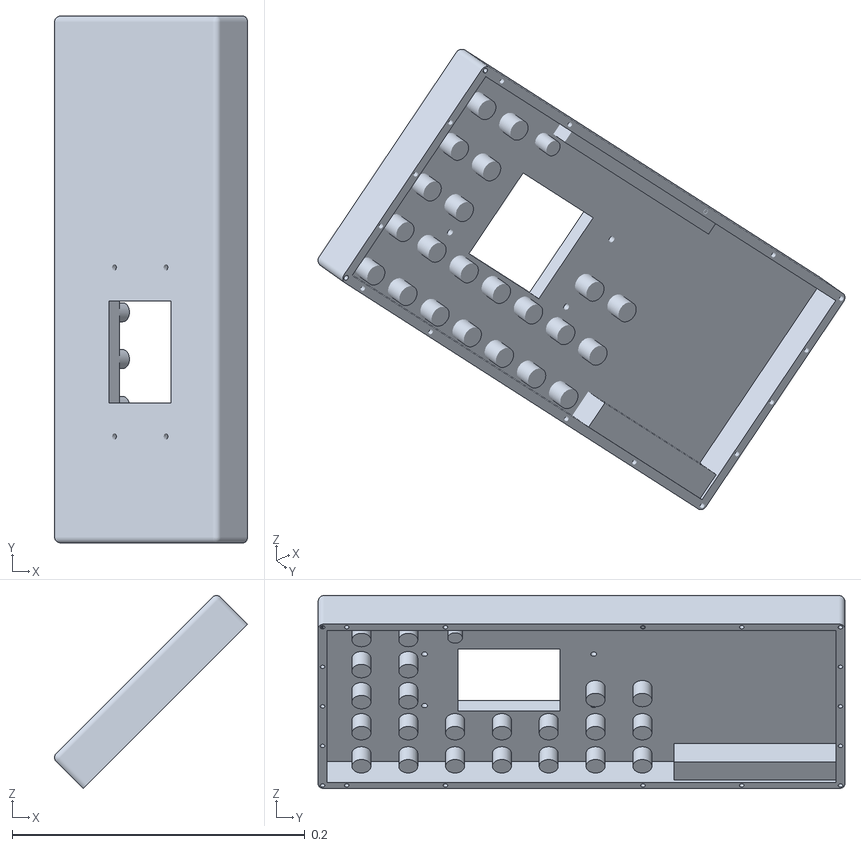
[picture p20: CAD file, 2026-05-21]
3D/Support tablette final.stl
0.132 x 0.36 x 0.132

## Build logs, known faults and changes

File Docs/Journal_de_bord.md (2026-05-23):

### Journal de bord

## 1e séance - 05/02/2026
* Présentation du projet et des objectifs attendus
* Choix du projet : K'Hess
* Création et prise en main de Github
* Prise en main du projet
* Discussion et état des lieux sur le projet 

## 2e séance - 12/02/2026
* Mise en place d'un schéma du projet
* Début de la schématique du PCB
* Début du travail sur l'interface utilisateur
* Recherche de Datasheets
* Recherche de composants

## 3e séance - 19/02/2026
* Schématique du PCB
* Travail sur Onshape pour la 3D
* Travail sur le code

## 4e séance - 12/03/2026
* Avancées sur le code
* Schématique du PCB
* Travail sur Onshape pour la 3D

## 5e séance - 19/03/2026
* Premières impressions tests 3D
* Schématique du PCB

## 6e séance - 26/03/2026
* Routage du PCB
* Codes du software

## 7e séance - 09/04/2026
* Routage du PCB
* Finition du PCB
* Travail sur la 3D
* Travail sur le code du module de payement

## 8e séance - 16/04/2026
* Finalisation du PCB
* Commande du PCB
* Travail sur le code du module de payement
* Travail sur la 3D

## 9e séance - 07/05/2026
* Recherche des composants
* Soudure du PCB
* Adaptation de la 3D à la taille des PCB

## 10e séance - 21/05/2026
* Test de l'ensemble
* Finitions 3D
* Mise à jour de Github
* Présentation du projet

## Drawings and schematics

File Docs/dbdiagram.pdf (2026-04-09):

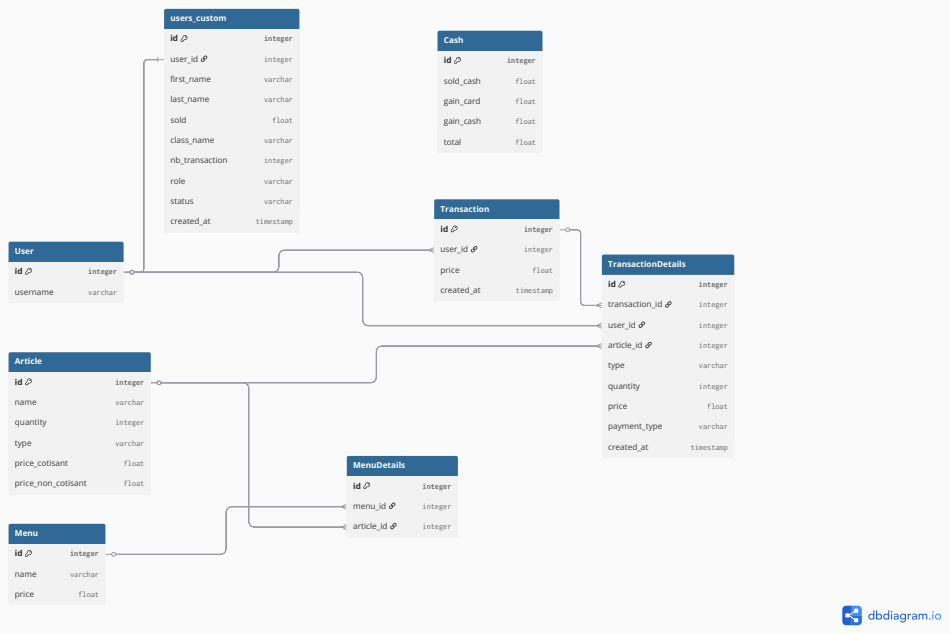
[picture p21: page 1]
User; integer; username; varchar; users_custom; user_id; first_name; last_name; sold; float; class_name; nb_transaction; role; status; created_at; timestamp; Article; name; quantity; type; price_cotisant; price_non_cotisant; Menu; price; MenuDetails; menu_id; article_id; Transaction; TransactionDetails; transaction_id; payment_type; Cash; sold_cash; gain_card; gain_cash; total

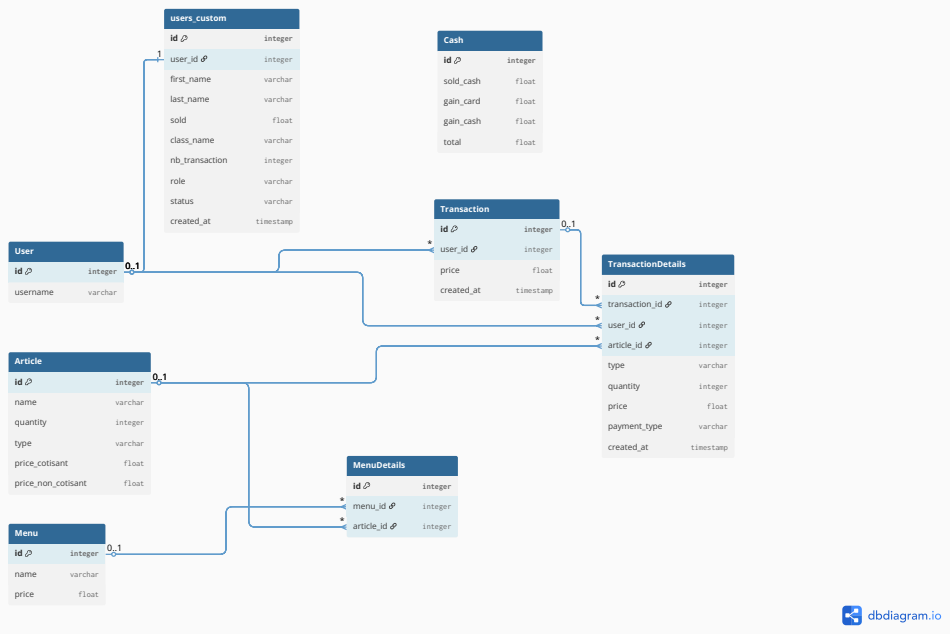
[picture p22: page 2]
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

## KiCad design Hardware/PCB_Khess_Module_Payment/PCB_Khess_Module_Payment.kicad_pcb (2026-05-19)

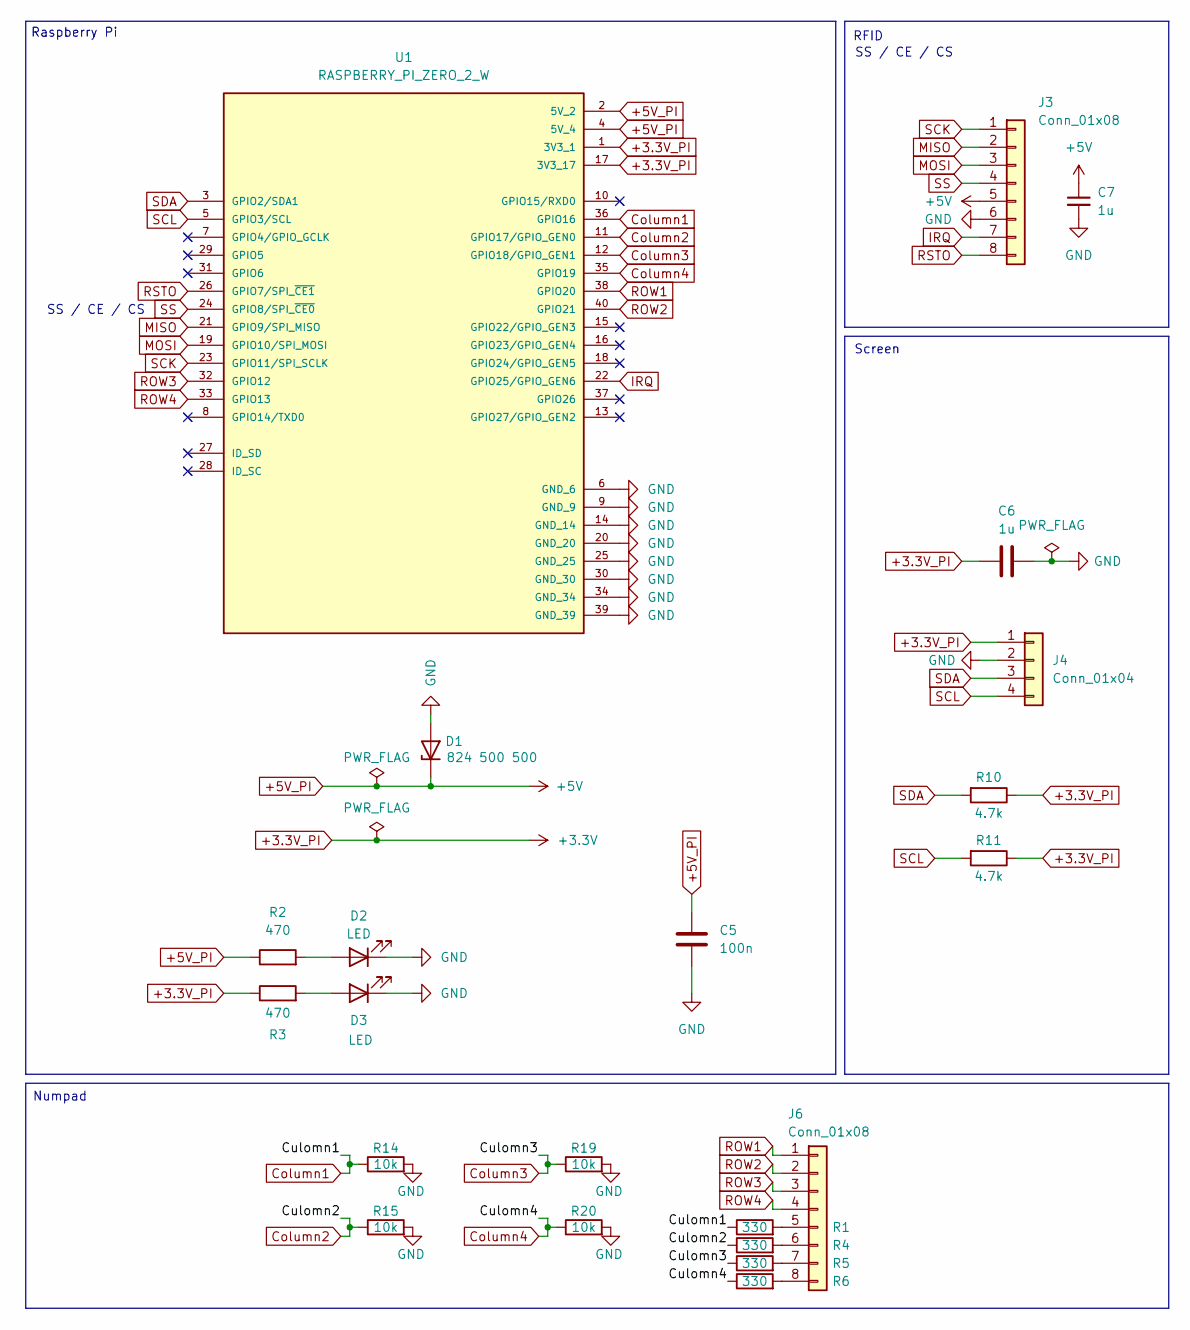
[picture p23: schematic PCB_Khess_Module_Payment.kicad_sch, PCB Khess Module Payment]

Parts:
C5: 100n; C_0402_1005Metric
C6, C7: 1u; C_0603_1608Metric
D1: 824 500 500; D_SMA
D2, D3: LED; LED_0603_1608Metric
J3, J6: Conn_01x08; PinHeader_1x08_P2.54mm_Horizontal
J4: Conn_01x04; PinHeader_1x04_P2.54mm_Horizontal
R1, R4, R5, R6: 330; R_0402_1005Metric
R2, R3: 470; R_0805_2012Metric
R10, R11: 4.7k; R_0402_1005Metric
R14, R15, R19, R20: 10k; R_0805_2012Metric
U1: RASPBERRY_PI_ZERO_2_W; MODULE_RASPBERRY_PI_ZERO_2_W; PARTREV April 2024

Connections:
+3.3V_PI: C6.1, J4.1, R3.1, R10.1, R11.1, U1.1 (3V3_1), U1.17 (3V3_17)
+5V_PI: C5.1, C7.1, D1.1 (K), J3.5, R2.1, U1.2 (5V_2), U1.4 (5V_4)
Column1: R1.1, R14.1, U1.36 (GPIO16)
Column2: R4.1, R15.1, U1.11 (GPIO17/GPIO_GEN0)
Column3: R5.1, R19.1, U1.12 (GPIO18/GPIO_GEN1)
Column4: R6.1, R20.1, U1.35 (GPIO19)
GND: C5.2, C6.2, C7.2, D1.2 (A), D2.1 (K), D3.1 (K), J3.6, J4.2, R14.2, R15.2, R19.2, R20.2, U1.6 (GND_6), U1.9 (GND_9), U1.14 (GND_14), U1.20 (GND_20), U1.25 (GND_25), U1.30 (GND_30), U1.34 (GND_34), U1.39 (GND_39)
IRQ: J3.7, U1.22 (GPIO25/GPIO_GEN6)
MISO: J3.2, U1.21 (GPIO9/SPI_MISO)
MOSI: J3.3, U1.19 (GPIO10/SPI_MOSI)
unnamed: D2.2 (A), R2.2
unnamed: D3.2 (A), R3.2
unnamed: J6.5, R1.2
unnamed: J6.6, R4.2
unnamed: J6.7, R5.2
unnamed: J6.8, R6.2
ROW1: J6.1, U1.38 (GPIO20)
ROW2: J6.2, U1.40 (GPIO21)
ROW3: J6.3, U1.32 (GPIO12)
ROW4: J6.4, U1.33 (GPIO13)
RSTO: J3.8, U1.26 (GPIO7/SPI_~CE1)
SCK: J3.1, U1.23 (GPIO11/SPI_SCLK)
SCL: J4.4, R11.2, U1.5 (GPIO3/SCL)
SDA: J4.3, R10.2, U1.3 (GPIO2/SDA1)
SS: J3.4, U1.24 (GPIO8/SPI_~CE0)

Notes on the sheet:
RFID
Raspberry Pi
Numpad
Screen
SS / CE / CS

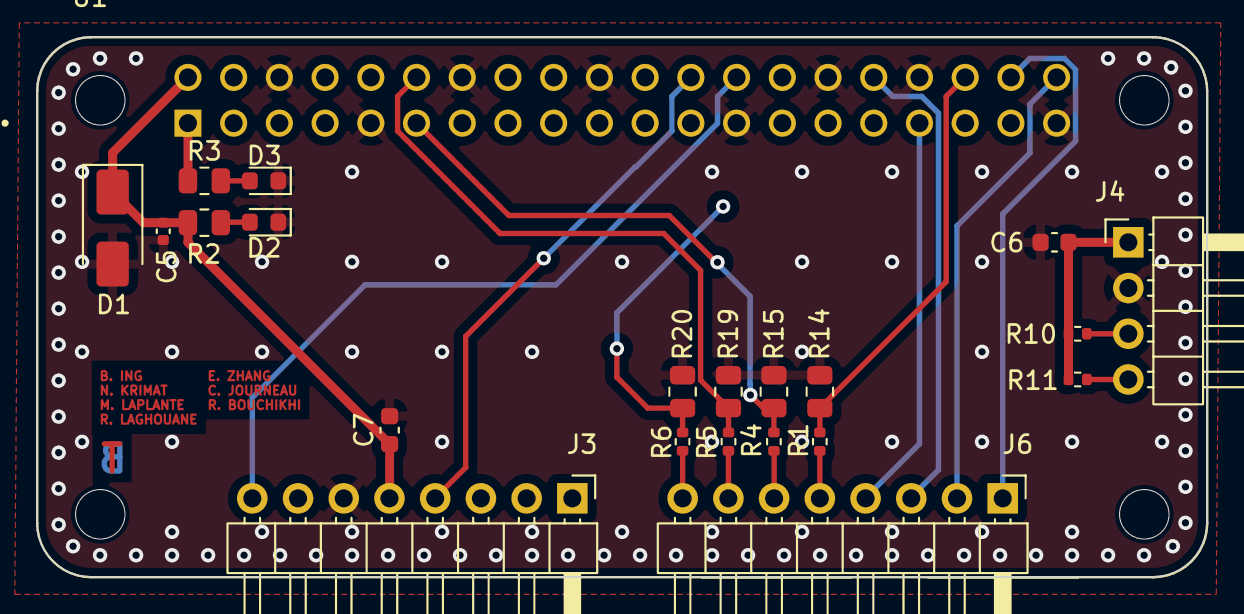
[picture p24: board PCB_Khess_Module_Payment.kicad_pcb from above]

Board: 4 copper layers, 65.0 x 30.0 mm, 22 parts (0 on the bottom side), 25 nets.

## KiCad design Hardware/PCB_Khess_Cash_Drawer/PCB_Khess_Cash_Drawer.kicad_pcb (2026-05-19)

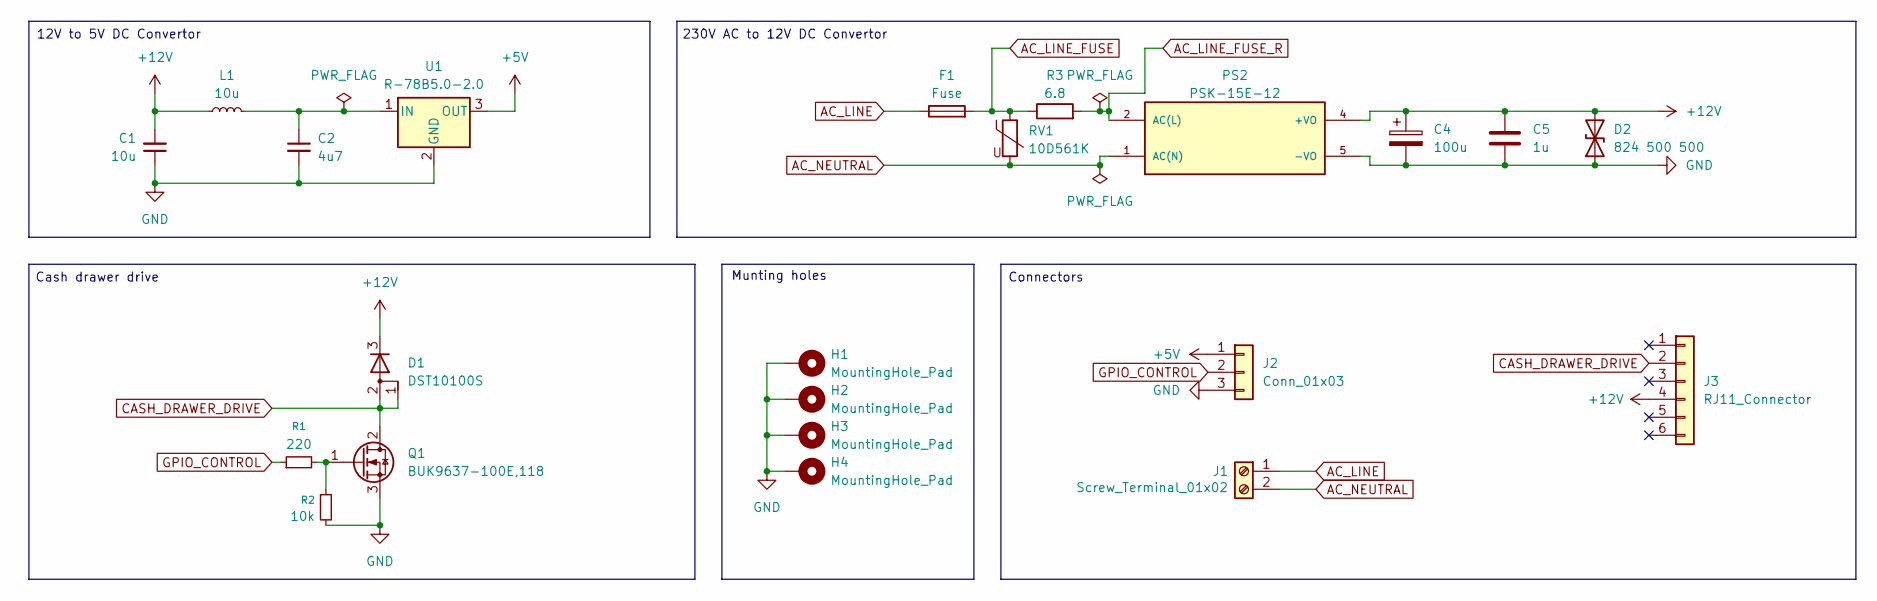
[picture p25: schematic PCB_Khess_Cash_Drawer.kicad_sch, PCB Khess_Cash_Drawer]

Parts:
C1: 10u; C_0805_2012Metric
C2: 4u7; C_0805_2012Metric
C4: 100u; CP_Elec_6.3x7.7
C5: 1u; C_0805_2012Metric
D1: DST10100S; TO-277A
D2: 824 500 500; D_SMA
F1: Fuse; Fuseholder_Cylinder-5x20mm_Schurter_0031_8201_Horizontal_Op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
H1, H2, H3, H4: MountingHole_Pad; MountingHole_2.7mm_M2.5_Pad
J1: Screw_Terminal_01x02; TerminalBlock_Phoenix_PT-1,5-2-5.0-H_1x02_P5.00mm_Horizontal
J2: Conn_01x03; PinHeader_1x03_P2.54mm_Vertical
J3: RJ11_Connector; RJ12_Amphenol_54601-x06_Horizontal
L1: 10u; L_0805_2012Metric
PS2: PSK-15E-12; CONV_PSK-15E-12; PARTREV 1.0
Q1: BUK9637-100E,118; TO-263-2
R1: 220; R_0603_1608Metric
R2: 10k; R_0603_1608Metric
R3: 6.8; R_Axial_DIN0414_L11.9mm_D4.5mm_P20.32mm_Horizontal
RV1: 10D561K; VAR_MOV-10D561K
U1: R-78B5.0-2.0; Converter_DCDC_RECOM_R-78B-2.0_THT

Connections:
+5V: J2.1, U1.3 (OUT)
+12V: C1.2, C4.1, C5.1, D1.3 (K), D2.2 (A2), J3.4, L1.1, PS2.4 (+VO)
AC_LINE: F1.1, J1.1
AC_LINE_FUSE: F1.2, R3.1, RV1.1
AC_LINE_FUSE_R: PS2.2 (AC(L)), R3.2
AC_NEUTRAL: J1.2, PS2.1 (AC(N)), RV1.2
CASH_DRAWER_DRIVE: D1.1 (A), D1.2 (A), J3.2, Q1.2 (D)
GND: C1.1, C2.2, C4.2, C5.2, D2.1 (A1), H1.1, H2.1, H3.1, H4.1, J2.3, PS2.5 (-VO), Q1.3 (S), R2.2, U1.2 (GND)
GPIO_CONTROL: J2.2, R1.1
unnamed: Q1.1 (G), R1.2, R2.1
unnamed: C2.1, L1.2, U1.1 (IN)

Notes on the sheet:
Connectors
230V AC to 12V DC Convertor
Munting holes
Cash drawer drive
12V to 5V DC Convertor

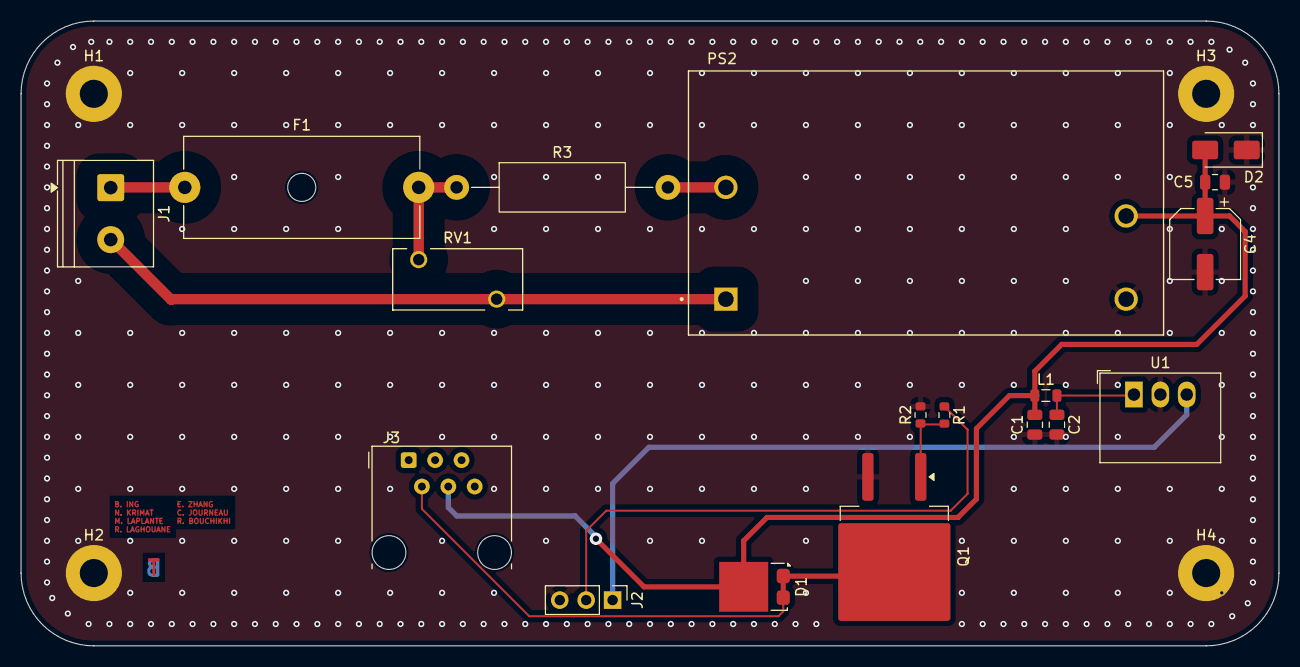
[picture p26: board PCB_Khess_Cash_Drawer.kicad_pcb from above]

Board: 2 copper layers, 121.0 x 60.1 mm, 22 parts (0 on the bottom side), 11 nets.

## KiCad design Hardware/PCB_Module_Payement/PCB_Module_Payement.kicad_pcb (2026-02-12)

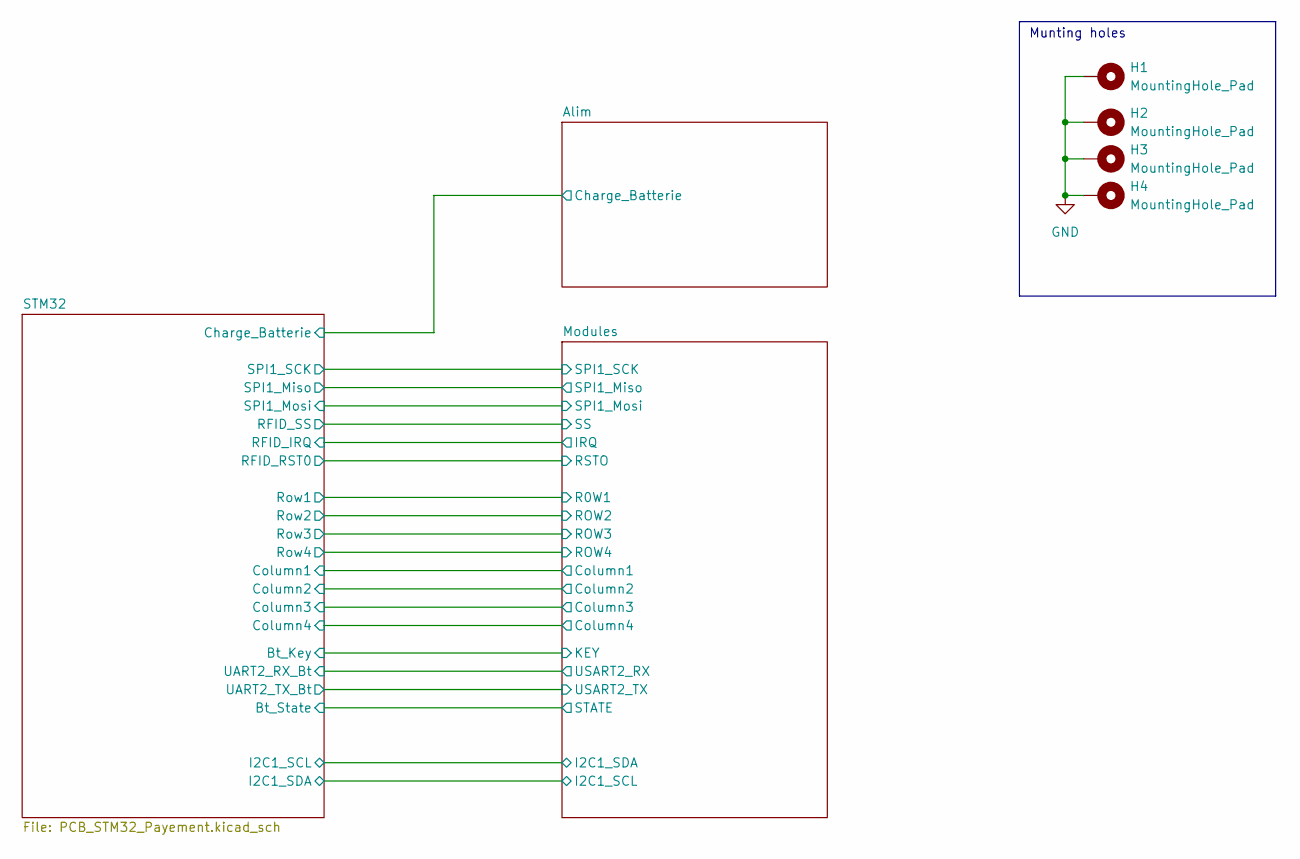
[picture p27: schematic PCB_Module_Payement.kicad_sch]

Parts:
H1, H2, H3, H4: MountingHole_Pad; MountingHole_2.7mm_M2.5_Pad

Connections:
GND: H1.1, H2.1, H3.1, H4.1; also elsewhere on the board

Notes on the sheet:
Munting holes

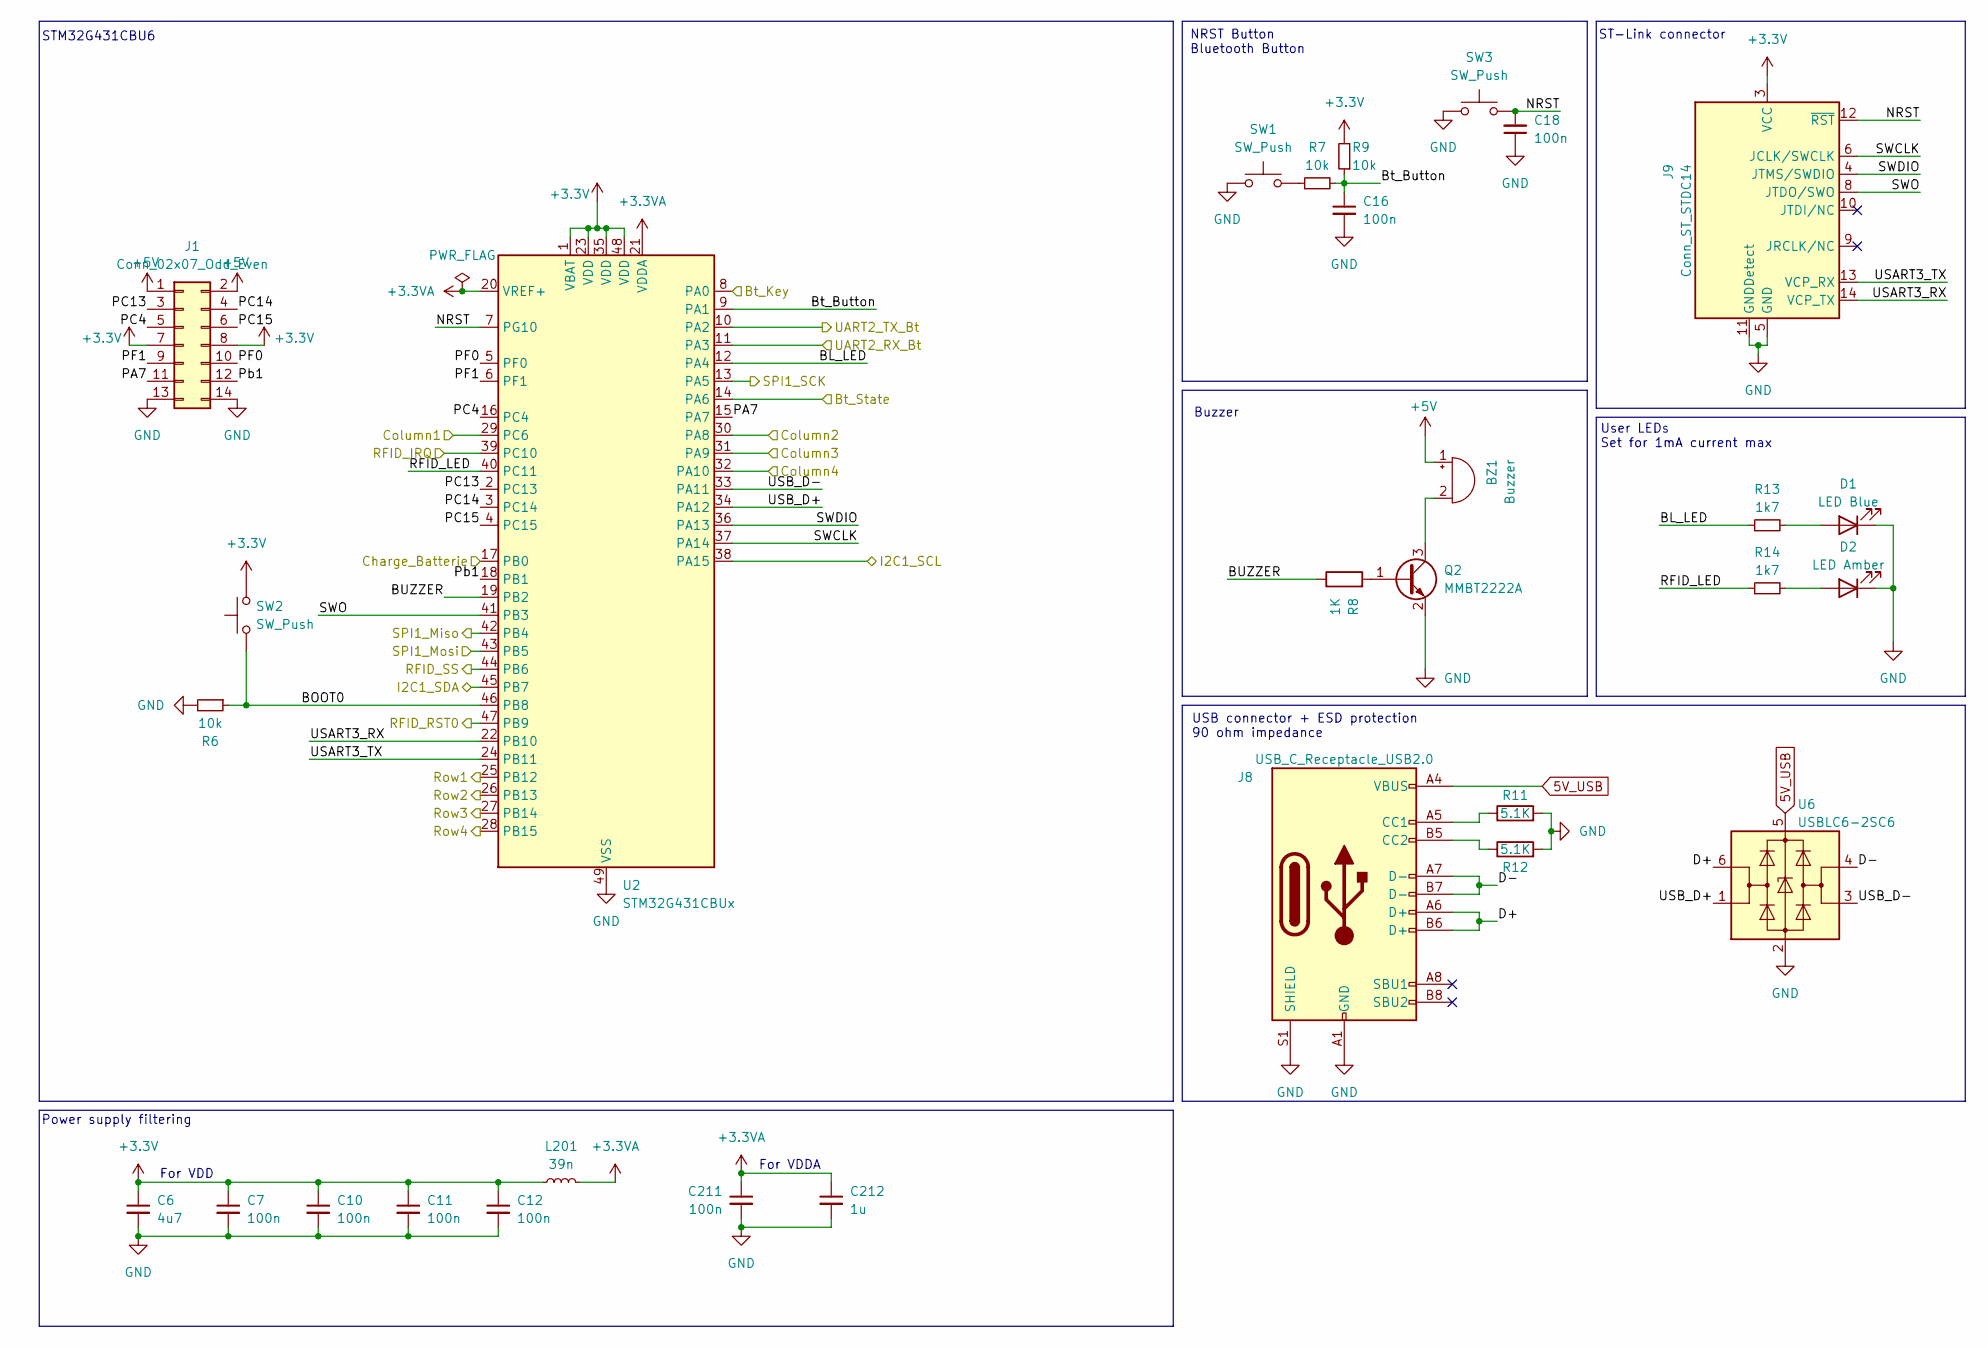
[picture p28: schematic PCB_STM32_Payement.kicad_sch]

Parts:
BZ1: Buzzer; Buzzer_12x9.5RM7.6
C6: 4u7; C_0402_1005Metric
C7, C10, C11, C12, C16, C18, C211: 100n; C_0402_1005Metric
C212: 1u; C_0603_1608Metric; MPN 885012105006
D1: LED Blue; LED_0603_1608Metric; MPN 150060RS55040
D2: LED Amber; LED_0603_1608Metric; MPN 150060AS55040
J1: Conn_02x07_Odd_Even; PinHeader_2x07_P2.54mm_Horizontal
J8: USB_C_Receptacle_USB2.0; USB_C_Receptacle_HRO_TYPE-C-31-M-12
J9: Conn_ST_STDC14; PinHeader_2x07_P1.27mm_Vertical_SMD
L201: 39n; L_0805_2012Metric
Q2: MMBT2222A; SOT-23
R6, R7, R9: 10k; R_0402_1005Metric
R8: 1K; R_0402_1005Metric
R11, R12: 5.1K; R_0402_1005Metric
R13, R14: 1k7; R_0402_1005Metric
SW1, SW2, SW3: SW_Push; SW_Push_1P1T_NO_CK_KSC6xxJ
U2: STM32G431CBUx; QFN-48-1EP_7x7mm_P0.5mm_EP5.6x5.6mm
U6: USBLC6-2SC6; SOT-23-6

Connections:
5V_USB: J8.A4 (VBUS), J8.A9 (VBUS), J8.B4 (VBUS), J8.B9 (VBUS), U6.5 (VBUS); also elsewhere on the board
+3.3V: C6.1, C7.1, C10.1, C11.1, C12.1, J1.7, J1.8, J9.3 (VCC), L201.1, R9.2, SW2.2, U2.1 (VBAT), U2.23 (VDD), U2.35 (VDD), U2.48 (VDD); also elsewhere on the board
+3.3VA: C211.1, C212.1, L201.2, U2.20 (VREF+), U2.21 (VDDA)
+5V: BZ1.1 (+), J1.1, J1.2; also elsewhere on the board
/Alim/Charge_Batterie: U2.17 (PB0); also elsewhere on the board
/Modules/Bt_RXD: U2.10 (PA2); also elsewhere on the board
/Modules/Bt_TXD: U2.11 (PA3); also elsewhere on the board
/Modules/Culomn1: U2.29 (PC6); also elsewhere on the board
/Modules/Culomn2: U2.30 (PA8); also elsewhere on the board
/Modules/Culomn3: U2.31 (PA9); also elsewhere on the board
/Modules/Culomn4: U2.32 (PA10); also elsewhere on the board
/Modules/I2C1_SCL: U2.45 (PB7); also elsewhere on the board
/Modules/I2C1_SDA: U2.38 (PA15); also elsewhere on the board
/Modules/IRQ: U2.39 (PC10); also elsewhere on the board
/Modules/KEY: U2.8 (PA0); also elsewhere on the board
/Modules/R0W1: U2.25 (PB12); also elsewhere on the board
/Modules/ROW2: U2.26 (PB13); also elsewhere on the board
/Modules/ROW3: U2.27 (PB14); also elsewhere on the board
/Modules/ROW4: U2.28 (PB15); also elsewhere on the board
/Modules/RSTO: U2.47 (PB9); also elsewhere on the board
/Modules/SPI1_Miso: U2.42 (PB4); also elsewhere on the board
/Modules/SPI1_Mosi: U2.43 (PB5); also elsewhere on the board
/Modules/SPI1_SCK: U2.13 (PA5); also elsewhere on the board
/Modules/SS: U2.44 (PB6); also elsewhere on the board
/Modules/STATE: U2.14 (PA6); also elsewhere on the board
/STM32/BL_LED: R13.1, U2.12 (PA4)
/STM32/BOOT0: R6.1, SW2.1, U2.46 (PB8)
/STM32/BUZZER: R8.1, U2.19 (PB2)
/STM32/Bt_Button: C16.1, R7.2, R9.1, U2.9 (PA1)
/STM32/D+: J8.A6 (D+), J8.B6 (D+), U6.6 (I/O1)
/STM32/D-: J8.A7 (D-), J8.B7 (D-), U6.4 (I/O2)
/STM32/NRST: C18.2, J9.12 (~RST), SW3.2, U2.7 (PG10)
/STM32/PA7: J1.11, U2.15 (PA7)
/STM32/PC4: J1.5, U2.16 (PC4)
/STM32/PC13: J1.3, U2.2 (PC13)
/STM32/PC14: J1.4, U2.3 (PC14)
/STM32/PC15: J1.6, U2.4 (PC15)
/STM32/PF0: J1.10, U2.5 (PF0)
/STM32/PF1: J1.9, U2.6 (PF1)
/STM32/Pb1: J1.12, U2.18 (PB1)
/STM32/RFID_LED: R14.1, U2.40 (PC11)
/STM32/SWCLK: J9.6 (JCLK/SWCLK), U2.37 (PA14)
/STM32/SWDIO: J9.4 (JTMS/SWDIO), U2.36 (PA13)
/STM32/SWO: J9.8 (JTDO/SWO), U2.41 (PB3)
/STM32/USART3_RX: J9.14 (VCP_TX), U2.22 (PB10)
/STM32/USART3_TX: J9.13 (VCP_RX), U2.24 (PB11)
/STM32/USB_D+: U2.34 (PA12), U6.1 (I/O1)
/STM32/USB_D-: U2.33 (PA11), U6.3 (I/O2)
GND: C6.2, C7.2, C10.2, C11.2, C12.2, C16.2, C18.1, C211.2, C212.2, D1.1 (K), D2.1 (K), J1.13, J1.14, J8.A1 (GND), J8.A12 (GND), J8.B1 (GND), J8.B12 (GND), J8.S1 (SHIELD), J9.5 (GND), J9.7 (GND), J9.11 (GNDDetect), Q2.2 (E), R6.2, R11.2, R12.2, SW1.1, SW3.1, U2.49 (VSS), U6.2 (GND); also elsewhere on the board
unnamed: BZ1.2 (-), Q2.3 (C)
unnamed: D1.2 (A), R13.2
unnamed: D2.2 (A), R14.2
unnamed: J8.A5 (CC1), R11.1
unnamed: J8.B5 (CC2), R12.1
unnamed: Q2.1 (B), R8.2
unnamed: R7.1, SW1.2

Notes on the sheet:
ST-Link connector
User LEDs Set for 1mA current max
NRST Button Bluetooth Button
For VDDA
For VDD
Power supply filtering
Buzzer
USB connector + ESD protection 90 ohm impedance
STM32G431CBU6

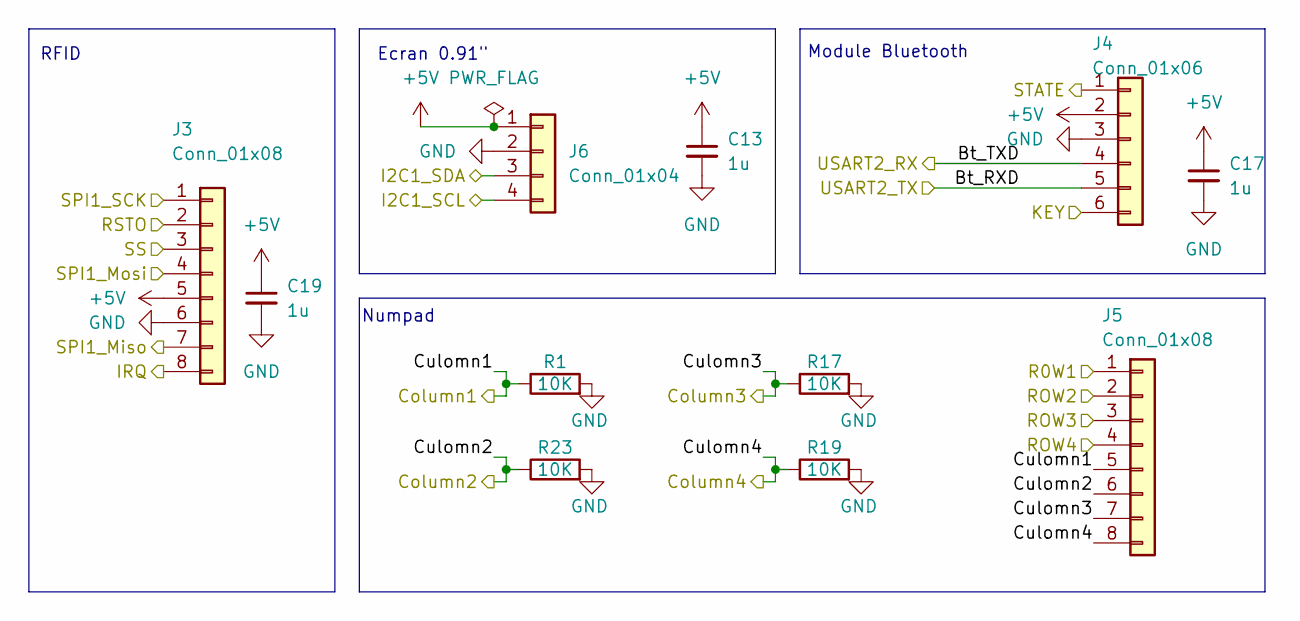
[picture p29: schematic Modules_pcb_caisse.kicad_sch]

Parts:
C13, C17, C19: 1u; C_0402_1005Metric
J3, J5: Conn_01x08; PinHeader_1x08_P2.54mm_Horizontal
J4: Conn_01x06; PinHeader_1x06_P2.54mm_Horizontal
J6: Conn_01x04; PinHeader_1x04_P2.54mm_Horizontal
R1, R17, R19, R23: 10K; R_0402_1005Metric

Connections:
+5V: C13.1, C17.1, C19.1, J3.5, J4.2, J6.1; also elsewhere on the board
/Modules/Bt_RXD: J4.5; also elsewhere on the board
/Modules/Bt_TXD: J4.4; also elsewhere on the board
/Modules/Culomn1: J5.5, R1.1; also elsewhere on the board
/Modules/Culomn2: J5.6, R23.1; also elsewhere on the board
/Modules/Culomn3: J5.7, R17.1; also elsewhere on the board
/Modules/Culomn4: J5.8, R19.1; also elsewhere on the board
/Modules/I2C1_SCL: J6.4; also elsewhere on the board
/Modules/I2C1_SDA: J6.3; also elsewhere on the board
/Modules/IRQ: J3.8; also elsewhere on the board
/Modules/KEY: J4.6; also elsewhere on the board
/Modules/R0W1: J5.1; also elsewhere on the board
/Modules/ROW2: J5.2; also elsewhere on the board
/Modules/ROW3: J5.3; also elsewhere on the board
/Modules/ROW4: J5.4; also elsewhere on the board
/Modules/RSTO: J3.2; also elsewhere on the board
/Modules/SPI1_Miso: J3.7; also elsewhere on the board
/Modules/SPI1_Mosi: J3.4; also elsewhere on the board
/Modules/SPI1_SCK: J3.1; also elsewhere on the board
/Modules/SS: J3.3; also elsewhere on the board
/Modules/STATE: J4.1; also elsewhere on the board
GND: C13.2, C17.2, C19.2, J3.6, J4.3, J6.2, R1.2, R17.2, R19.2, R23.2; also elsewhere on the board

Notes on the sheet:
Numpad
RFID
Module Bluetooth
Ecran 0.91"

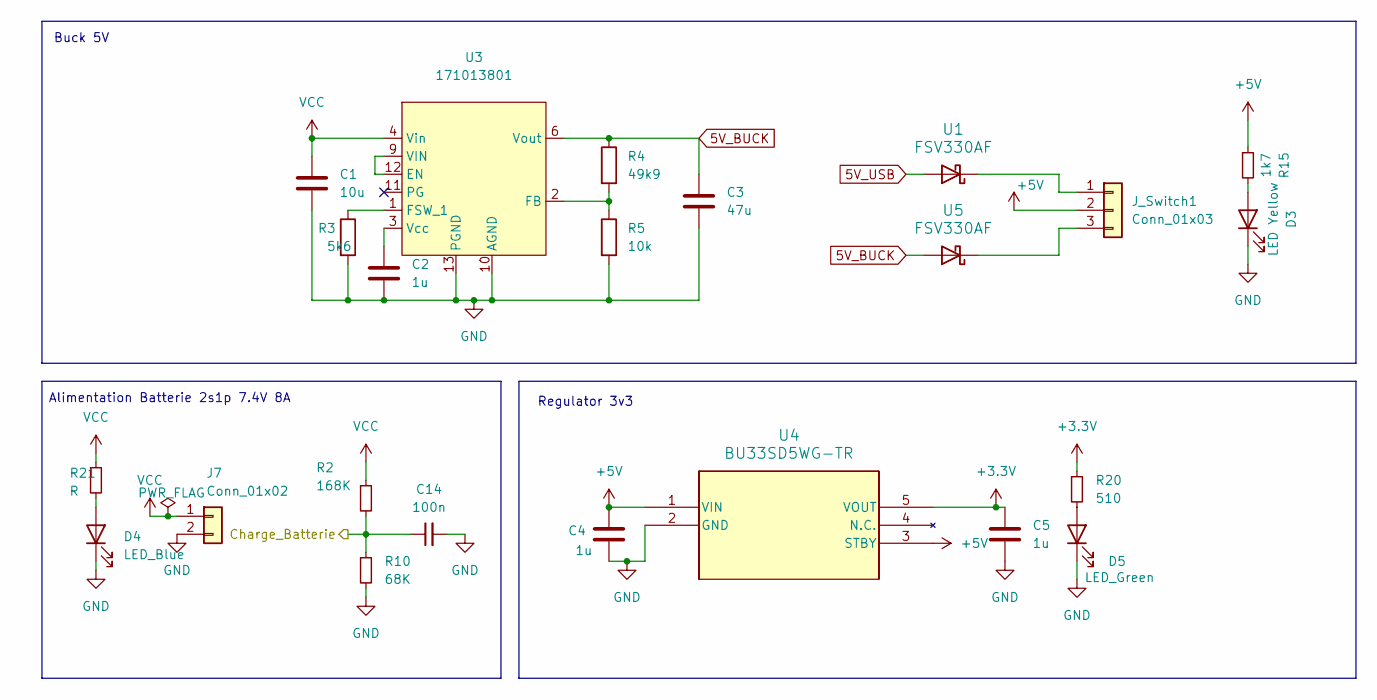
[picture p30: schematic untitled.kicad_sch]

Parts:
C1: 10u; C_0805_2012Metric
C2, C4, C5: 1u; C_0402_1005Metric
C3: 47u; C_0805_2012Metric
C14: 100n; C_0402_1005Metric
D3: LED Yellow; LED_0603_1608Metric; MPN 150060YS55040
D4: LED_Blue; LED_0603_1608Metric
D5: LED_Green; LED_0603_1608Metric
J7: Conn_01x02; JST_XA_S02B-XASK-1_1x02_P2.50mm_Horizontal
J_Switch1: Conn_01x03; JST_XA_S03B-XASK-1_1x03_P2.50mm_Horizontal
R2: 168K; R_0402_1005Metric
R3: 5k6; R_0402_1005Metric
R4: 49k9; R_0402_1005Metric
R5: 10k; R_0402_1005Metric
R10: 68K; R_0402_1005Metric
R15: 1k7; R_0402_1005Metric
R20: 510; R_0402_1005Metric
R21: R; R_0402_1005Metric
U1, U5: FSV330AF; DO-214AD_ONS; MPN FSV330AF
U3: 171013801; Wurth_171013801; MPN 171013801
U4: BU33SD5WG-TR; SSOP5_ROM

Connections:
5V_BUCK: C3.1, R4.1, U3.6 (Vout), U3.7 (Vout), U5.2 (A)
5V_USB: U1.2 (A); also elsewhere on the board
+3.3V: C5.2, R20.1, U4.5 (VOUT); also elsewhere on the board
+5V: C4.1, J_Switch1.2, R15.1, U4.1 (VIN), U4.3 (STBY); also elsewhere on the board
/Alim/Charge_Batterie: C14.1, R2.2, R10.1; also elsewhere on the board
GND: C1.2, C2.2, C3.2, C4.2, C5.1, C14.2, D3.1 (K), D4.1 (K), D5.1 (K), J7.2, R3.2, R5.2, R10.2, U3.10 (AGND), U3.13 (PGND), U4.2 (GND); also elsewhere on the board
unnamed: D3.2 (A), R15.2
unnamed: D4.2 (A), R21.2
unnamed: D5.2 (A), R20.2
unnamed: J_Switch1.1, U1.1 (K)
unnamed: J_Switch1.3, U5.1 (K)
unnamed: U3.9 (VIN), U3.12 (EN)
unnamed: R4.2, R5.1, U3.2 (FB)
unnamed: R3.1, U3.1 (FSW_1)
unnamed: C2.1, U3.3 (Vcc)
VCC: C1.1, J7.1, R2.1, R21.1, U3.4 (Vin), U3.5 (Vin)

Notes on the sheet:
Alimentation Batterie 2s1p 7.4V 8A
Regulator 3v3
Buck 5V

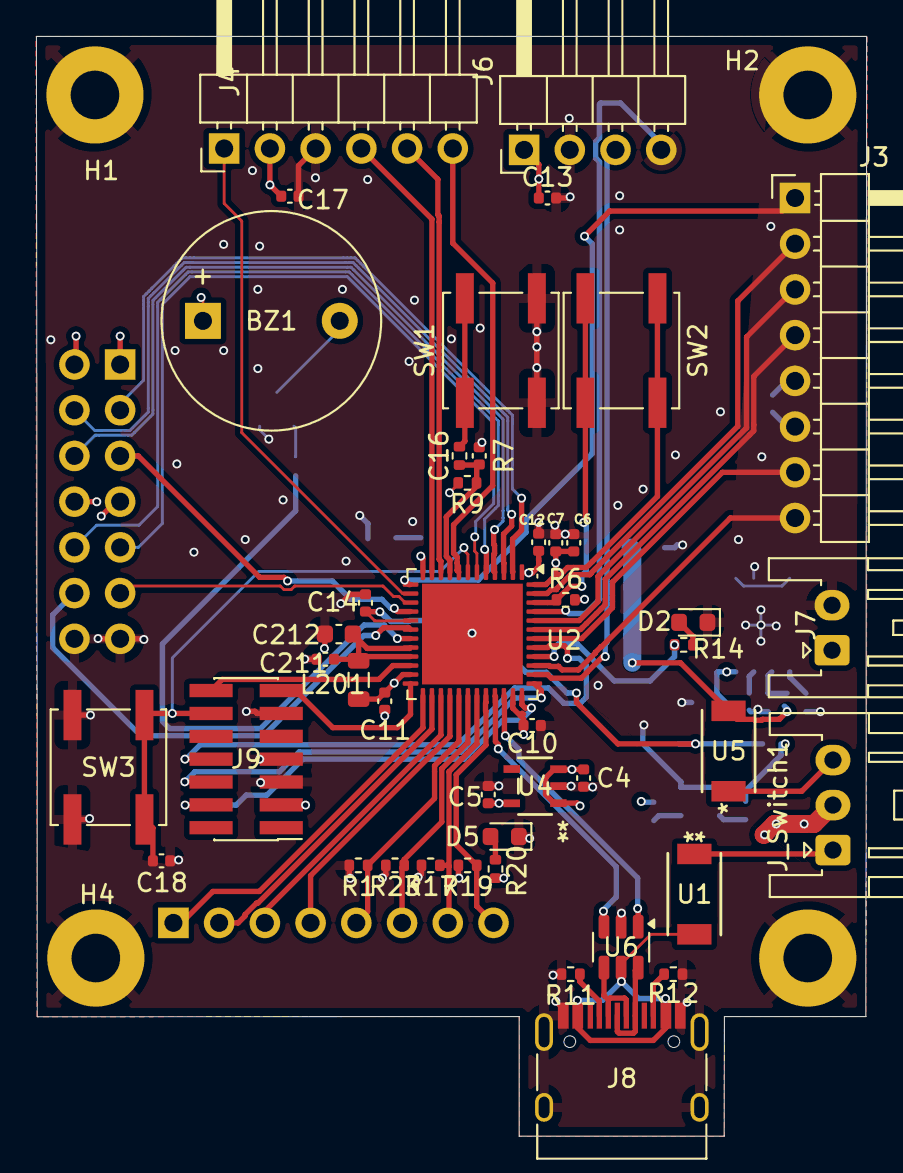
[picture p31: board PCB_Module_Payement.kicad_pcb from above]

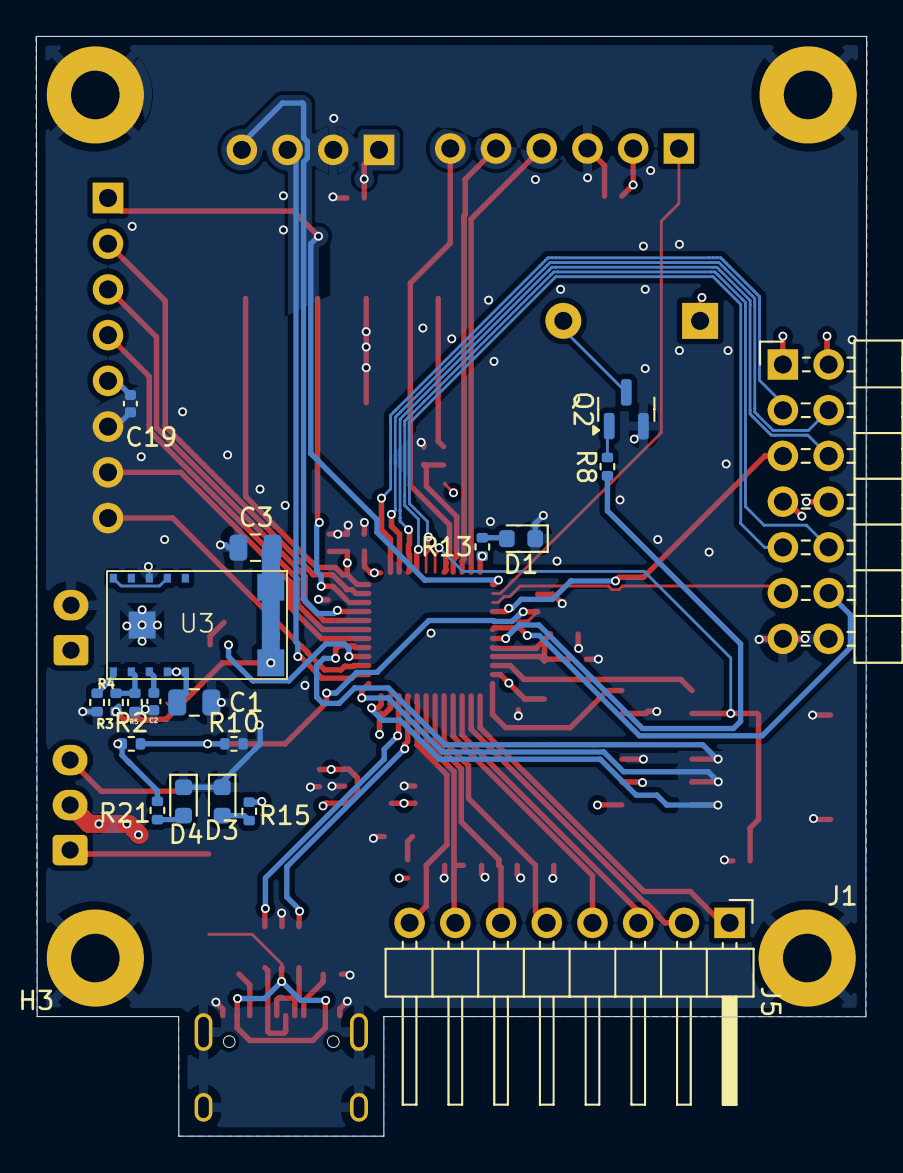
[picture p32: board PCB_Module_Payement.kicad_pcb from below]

Board: 4 copper layers, 46.1 x 61.1 mm, 68 parts (20 on the bottom side), 67 nets.

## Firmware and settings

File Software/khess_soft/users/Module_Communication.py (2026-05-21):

"""
Communication Bluetooth RFCOMM avec le matériel de la KFET.
Le module envoie une commande texte au HC-05 puis récupère une réponse éventuelle.
"""
import socket


def send_bluetooth_command(address, command):
    """
    Envoie une commande texte à un périphérique Bluetooth RFCOMM.

    :param address: Adresse MAC du périphérique.
    :param command: Commande à envoyer.
    :return: Réponse du périphérique, ou message d'erreur lisible.
    """
    sock = None
    try:
        sock = socket.socket(socket.AF_BLUETOOTH, socket.SOCK_STREAM, socket.BTPROTO_RFCOMM)
        sock.settimeout(5.0)

        # Le HC-05 utilise généralement le canal 1.
        sock.connect((address, 1))
        sock.sendall(command.encode('utf-8'))

        response = ""
        while True:
            try:
                data = sock.recv(1024)
                if not data:
                    break

                decoded = data.decode('utf-8', errors='replace')
                response += decoded

                if '\n' in decoded:
                    break
            except socket.timeout:
                break

        return response.strip() if response.strip() else "Envoyé"

    except Exception as e:
        return f"Erreur Bluetooth : {e}"

    finally:
        if sock:
            sock.close()
'''
"""
Ce module est indépendant de Django. Son seul rôle est de parler avec 
le matériel physique de la KFET (le module Bluetooth HC-05 connecté à un Arduino/Raspberry).
"""
import socket

def send_bluetooth_command(address, command):
    """
    Ouvre une connexion sans fil, envoie un texte, et referme la connexion.

    :param address: Adresse MAC du périphérique Bluetooth (HC-05 ou autre).
    :param command: Commande à envoyer (chaîne de caractères).
    :return: Réponse du périphérique (si disponible).
    """
    sock = None
    try:
        # Création d'une "prise" virtuelle pour le Bluetooth (RFCOMM)
        sock = socket.socket(socket.AF_BLUETOOTH, socket.SOCK_STREAM, socket.BTPROTO_RFCOMM)
        
        # SÉCURITÉ : limite de temps (5 secondes)
        sock.settimeout(5.0) 
        
        # Connexion à l'adresse MAC sur le canal 1
        sock.connect((address, 1))
        print(f"Connecté à {address}")
        
        # Envoi de la commande
        sock.send(command.encode())
        print(f"Commande envoyée : {command}")

        # Lecture de la réponse
        response = ""
        n = 0
        while n < 15:
            n += 1
            try:
                data = sock.recv(1024).decode('utf-8')
                response += data
                if '\n' in data:  # Fin de message
                    break
            except socket.timeout:
                # Pas de réponse dans le délai
                break
        
        return response if response else "Envoyé (pas de réponse du matériel)"

    except Exception as e:
        return f"Erreur Bluetooth : {e}"

    finally:
        # Fermeture propre de la connexion
        if sock:
            sock.close()


if __name__ == "__main__":
    address = "98:D3:41:F6:FF:4F"  # Remplacez par l'adresse MAC de votre HC-05
    command = "Votrecomma"         # Remplacez par la commande à envoyer

    response = send_bluetooth_command(address, command)
    print(response)


"""
Ce module est indépendant de Django. Son seul rôle est de parler avec 
le matériel physique de la KFET (le module Bluetooth HC-05 connecté à un Arduino/Raspberry).
"""
import socket

def send_bluetooth_command(address, command):
    """
    Ouvre une connexion sans fil, envoie un texte, et referme la connexion.
    """
        """
    Envoie une commande au périphérique Bluetooth via BLE.
    :param address: Adresse MAC du périphérique Bluetooth (HC-05 ou autre).
    :param command: Commande à envoyer (chaîne de caractères).
    :return: Réponse du périphérique (si disponible).
    """
    try:
        # Création d'une "prise" virtuelle pour le Bluetooth (RFCOMM)
        sock = socket.socket(socket.AF_BLUETOOTH, socket.SOCK_STREAM, socket.BTPROTO_RFCOMM)
        
        # SÉCURITÉ : On impose une limite de temps (5 secondes). 
        # Si le module Bluetooth est éteint, le site web n'attendra pas à l'infini et ne plantera pas.
        sock.settimeout(5.0) 
        
        # On se connecte à l'adresse MAC fournie, sur le canal 1
        sock.connect((address, 1))
        print(f"Connecté à {address}")
        
        # On encode le texte en "octets" pour qu'il puisse voyager dans les ondes, puis on l'envoie.
        sock.send(command.encode())
        print(f"Commande envoyée : {command}")

        # Lire une réponse (si nécessaire)
        response = ""
        n=0
        while n<15:
            n+=1
            data = sock.recv(1024).decode('utf-8')
            response += data
            if '\n' in data:  # Arrêter la lecture si le caractère de fin est détecté
                break
        
        # Fermer la connexion
        sock.close()
        
        return response
    except Exception as e:
        return f"Erreur : {e}"

        try:
            # On écoute pour voir si l'Arduino nous répond "OK"
            response = sock.recv(1024).decode('utf-8')
        except socket.timeout:
            # Si l'Arduino ne répond pas assez vite, on considère que c'est envoyé quand même.
            response = "Envoyé (pas de réponse du matériel)"
            
        sock.close() # On coupe la communication proprement
        return response
        
    except Exception as e:
        # Si le Bluetooth est éteint ou hors de portée, on renvoie une erreur lisible.
        return f"Erreur Bluetooth : {str(e)}"
        return f"Erreur : {e}"
    
if __name__ == "__main__":
    address = "98:D3:41:F6:FF:4F" # Remplacez par l'adresse MAC de votre HC-05
    command = "Votrecomma" # Remplacez par la commande que vous voulez envoyer
    response = send_bluetooth_command(address, command)
    print(response)

    '''

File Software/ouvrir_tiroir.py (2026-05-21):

import time
from gpiozero import OutputDevice

GPIO_PIN = 17

# 2. Initialisation de la broche de contrôle
# active_high=True signifie qu'un signal 3.3V active le MOSFET
tiroir_caisse = OutputDevice(GPIO_PIN, active_high=True, initial_value=False)

def ouvrir_tiroir():
    print("Envoi du signal d'ouverture...")
    
    # Active le GPIO (Envoie du 3.3V au MOSFET)
    tiroir_caisse.on()

    time.sleep(0.2) 
    
    # Désactive le GPIO (Retour à 0V)
    tiroir_caisse.off()
    
    print("Tiroir-caisse déverrouillé avec succès.")

if __name__ == "__main__":
    ouvrir_tiroir()

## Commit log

2026-02-06 docs(contributing): ajouter un guide de contribution et format de commit
2026-02-12 feat: ajout dossier KiCad
    [Modules_pcb_caisse.kicad_sch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]
2026-02-12 Revise Brouillon with LCD and Raspberry Pi details
    Updated the draft with details about the LCD control card and Raspberry Pi connections.
2026-02-12 Add details about Raspberry Pi connections and cables
2026-02-12 fix: correction dossier hardware
    [Modules_pcb_caisse.kicad_sch, PCB_Module_Payement.kicad_sch, PCB_STM32_Payement.kicad_sch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]
2026-02-12 chore: supression de Software/.gitkeep
2026-02-12 feat: add Raspberry Pi Zero 2 W to components list in README
2026-02-19 feat: add PCB_Khess KiCad files
    Add a new KiCad project for PCB_Khess
    [PCB_Khess.kicad_pcb, PCB_Khess.kicad_sch]
2026-02-19 fix: add name pcb
    [PCB_Khess.kicad_sch]
2026-02-19 feat: update pcb cash register and add datasheet
    [IRF540NPBF.step, PCB_Khess.kicad_sch]
2026-02-19 chore: change folder name
    [Composants.xlsx, Modules_pcb_caisse.kicad_sch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]
2026-02-19 fix: update pcb main
    [IRF540NPBF.step, PCB_Khess.kicad_sch]
2026-02-19 Update Brouillon with additional notes
    Added notes on cable connections and user handling.
2026-02-19 fix: update pcb
    [PCB_Khess.kicad_sch]
2026-02-19 Schéma de la base de données
2026-02-20 feat: add pcb routing terminal payment
    [Pcb_caisse_raspberry.kicad_pcb]
2026-02-20 feat: update all pcb and schematic
    [PCB_Khess.kicad_pcb, PCB_Khess.kicad_sch, Pcb_caisse_raspberry.kicad_pcb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]
2026-03-06 feat: update schematic
    [PCB_Khess_Cash_Drawer.kicad_pcb, PCB_Khess_Cash_Drawer.kicad_sch, PCB_Khess_Module_Payment.kicad_pcb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]
2026-03-12 fix: fix pcb cash drawer
    [PCB_Khess_Cash_Drawer.kicad_pcb]
2026-03-12 fix: fix pcb
    [MOV-10D561K.step, PCB_Khess_Cash_Drawer.kicad_pcb, PCB_Khess_Cash_Drawer.kicad_sch]
2026-03-19 fix: update module payment schematic
    [PCB_Khess_Module_Payment.kicad_sch, TP5100.step]
2026-03-19 fix: update connector rfid module payment
    [PCB_Khess_Module_Payment.kicad_sch]
2026-03-19 fix: usb c to 12v dc barel jack connector
    [PCB_Khess_Module_Payment.kicad_sch]
2026-03-25 fix: update schematic
    [PCB_Khess_Module_Payment.kicad_sch]
2026-03-26 review schematics
    [PCB_Khess_Cash_Drawer.kicad_sch, PCB_Khess_Module_Payment.kicad_sch]
2026-03-26 fix: update schematic with footprint
    [PCB_Khess_Module_Payment.kicad_sch]
2026-03-26 feat: improve schematic
    [PCB_Khess_Module_Payment.kicad_pcb]
2026-04-09 fix: update schematic and footprint
    [PCB_Khess_Module_Payment.kicad_sch]
2026-04-09 feat: suply via shield
    [PCB_Khess_Module_Payment.kicad_sch]
2026-04-09 Create schéma de la base de donnée dbdiagram.md
2026-04-09 Update schéma de la base de donnée dbdiagram.md
2026-04-09 feat: shield pcb raspberry
    [PCB_Khess_Module_Payment.kicad_pcb, PCB_Khess_Module_Payment.kicad_sch]
2026-04-09 fix: update
    [PCB_Khess_Cash_Drawer.kicad_pcb]
2026-04-10 fix: update PCB_Khess_Module_Payment
    [PCB_Khess_Module_Payment.kicad_pcb, PCB_Khess_Module_Payment.kicad_sch]
2026-04-12 fix: update two pcb and add gnd via
    [PCB_Khess_Cash_Drawer.kicad_pcb, PCB_Khess_Cash_Drawer.kicad_sch, PCB_Khess_Module_Payment.kicad_pcb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]
2026-04-12 fix: update pcb routing
    [PCB_Khess_Cash_Drawer.kicad_pcb]
2026-04-13 fix: pcb
    [PCB_Khess_Module_Payment.kicad_pcb]
2026-04-13 fix: add gnd to all plan
    [PCB_Khess_Module_Payment.kicad_pcb]
2026-04-13 feat: add gerbers
    [PCB_Khess_Cash_Drawer-B_Cu.gbr, PCB_Khess_Cash_Drawer-B_Mask.gbr, PCB_Khess_Cash_Drawer-B_Paste.gbr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]
2026-04-15 refractor: remove old kicad folder
    [Composants.xlsx, Modules_pcb_caisse.kicad_sch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]
2026-05-12 feat: case cash drawer with turbocase
    [PCB_Khess_Cash_Drawer.kicad_pcb, case.scad, case.stl]
2026-05-19 feat: add readme
    [PCB_Khess_Cash_Drawer.step, case.stl, case_lid.stl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]
2026-05-19 feat: add PCB schematic for Cash Drawer
    Added PCB schematic image
2026-05-19 add: update PCB schematic
2026-05-19 docs: KiCad PCBs, exports and README
    [PCB_Khess_Cash_Drawer.kicad_pcb, PCB_Khess_Module_Payment.kicad_pcb]
2026-05-21 docs: update README links
    [Caisse entière avec socle.stl, Module payement final.stl, Support tablette final.stl]
2026-05-21 Update README.md
    choix des composants
2026-05-21 Update README.md
    choix des composants PCB_Module_Paiement
2026-05-23 Rename journal_de_bord.md to Journal de bord.md
2026-05-23 Rename Journal de bord.md to Journal_de_bord.md
